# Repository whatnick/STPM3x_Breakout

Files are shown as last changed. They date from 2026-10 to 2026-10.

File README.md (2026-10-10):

# STPM3x Energy Metering Breakouts

Open-hardware development boards for the STMicroelectronics STPM32, STPM33,
and STPM34 energy-metering ASIC family.

The STPM3x devices combine precision analog conversion with on-chip
calculation of voltage, current, power, energy, and power-quality events. They
support current transformers, shunts, and Rogowski coils, with SPI or UART
host communication and CRC-protected data transfers.

This repository develops a consistent breakout family around all three channel
configurations:

| Board | Measurement channels | Best fit |
|---|---|---|
| **STPM32 Breakout** | 1 voltage + 1 current | Single-phase meters, smart appliances, and compact sensor development |
| **STPM33 Breakout** | 1 voltage + 2 current | Phase/neutral monitoring, tamper detection, and dual-current experiments |
| **STPM34 Breakout** | 2 voltage + 2 current | Split-phase systems, two independent circuits, and two-phase monitoring |

The STPM34 is the most capable member of this family, but it is not a complete
three-phase meter by itself. Applications requiring three simultaneous voltage
and current phases are better served by devices such as the ADE9000 or
ATM90E36.

## Place in the Whatnick ecosystem

The Whatnick energy-monitoring ecosystem includes breakout boards and drivers
for several metering architectures:

- **ATM90E26** for established single-phase SPI metering.
- **ATM90E32/ATM90E36** for three-phase monitoring.
- **ADE7763 and ADE7816** for Analog Devices single- and multi-channel designs.
- **ADE9000** for advanced polyphase metering and power-quality work.
- **CS5464 and CS5490** for Cirrus Logic single-phase applications.
- **MCP39F511 and MCP39F521** for Microchip calculation-engine devices.
- **V9203 and V93xx** for additional polyphase and single-phase platforms.
- **STPM3x** for a scalable STMicroelectronics family using a common register
  model across single-, dual-current, and dual-channel applications.

The aim is not only to expose IC pins. Each breakout should provide a known
hardware platform for driver development, calibration tools, sensor-interface
experiments, waveform analysis, and comparison between metering ASIC families.

## Intended software ecosystem

The three boards are intended to share one transport-independent STPM3x driver
core with device-specific channel capabilities layered on top. Planned software
support includes:

- Register definitions and typed configuration helpers.
- SPI and UART transports.
- CRC generation and checking.
- RMS, power, energy, event, and status access.
- Calibration and register-dump tools.
- Arduino and Python/MicroPython-facing APIs.
- Examples for CT, shunt, and Rogowski-coil measurements.

Keeping a common API across STPM32, STPM33, and STPM34 will allow applications
to move between board variants without maintaining three unrelated drivers.

## Hardware philosophy

These boards are intended as accessible bench-development platforms:

- Clearly separated analog sensor and digital host interfaces.
- Exposed pulse, interrupt, synchronization, clock, and enable signals.
- Space for channel-specific burden, divider, protection, and filtering
  networks.
- 3.3 V host compatibility.
- Compact breadboard modules or larger bench boards according to channel count.
- Readable safety labels and accessible test points.
- Open KiCad 10 source and project-local STPM3x symbols.

The STPM32 variant implements a complete compact front end for a
100 A:50 mA current-output CT and an isolated 9 VAC transformer secondary. It
uses a single 1x12 breadboard header, underside test pads, separate analog and
digital ground pours, and no field-wiring connectors. The STPM33 variant is
also complete, using the same isolated 9 VAC input with two 100 A:50 mA CT
channels, a 1x14 development header, five underside test pads, and a 55 x 40 mm
bench-board envelope. The STPM34 variant is complete on a 75 x 50 mm bench
board with two isolated 9 VAC channels, two 100 A:50 mA CT channels, separate
analog and host headers, and three underside test pads.

## Repository contents

- [`hardware/STPM32_Breakout`](hardware/STPM32_Breakout) - single voltage and
  current channel.
- [`hardware/STPM33_Breakout`](hardware/STPM33_Breakout) - single voltage and
  dual current channels.
- [`hardware/STPM34_Breakout`](hardware/STPM34_Breakout) - dual voltage and
  current channels.
- [`symbols/STPM3x.kicad_sym`](symbols/STPM3x.kicad_sym) - project-local,
  datasheet-verified symbols.
- [`docs/pin-map.md`](docs/pin-map.md) - family pin and package comparison.
- [`docs/design-requirements.md`](docs/design-requirements.md) - shared
  electrical, mechanical, and safety requirements.

## Safety

These are development boards, not certified energy meters. They must not be
connected directly to hazardous voltages without correctly rated isolation,
protection, fusing, spacing, enclosure, and appropriate electrical-safety
practices.

## License

Hardware design files are released under the
[TAPR Open Hardware License 1.0](LICENSE).

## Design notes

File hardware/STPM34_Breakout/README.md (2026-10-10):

# STPM34 Breakout

KiCad 10 open-hardware breakout for the STMicroelectronics STPM34 metering
ASIC. It measures two isolated voltage channels and two current-transformer
channels for split-phase, dual-circuit, and two-phase development.

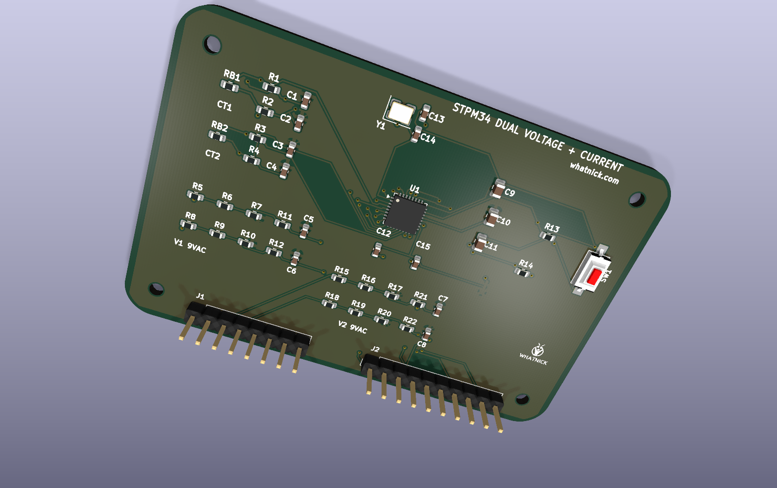
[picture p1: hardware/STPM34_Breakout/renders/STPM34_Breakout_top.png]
Top render


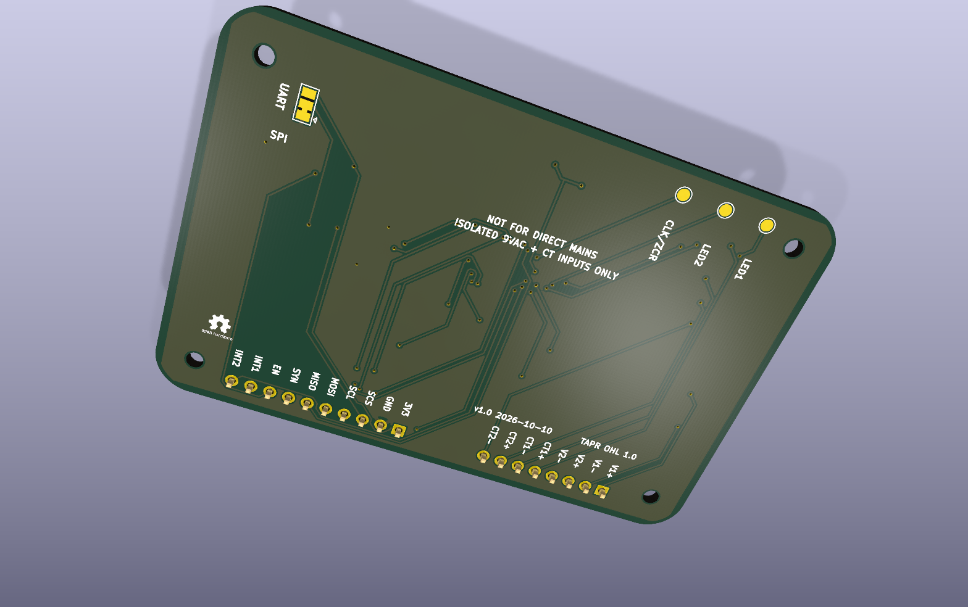
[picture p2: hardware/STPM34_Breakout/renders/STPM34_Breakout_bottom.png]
Bottom render


## Front end

- Supply: 3.3 V.
- Voltage inputs: two isolated 9 VAC transformer secondaries.
- Current inputs: two 100 A:50 mA CTs.
- Current burdens: 2.4 ohm differential, giving 120 mV RMS at 100 A.
- Current filters: 100 ohm series resistors and 330 nF capacitors.
- Voltage dividers: symmetric 200 kohm / 2.49 kohm per channel.
- Voltage filters: 1 kohm series resistors and 33 nF capacitors.
- Clock: 16 MHz crystal.
- Grounding: separate GNDA and DGND pours joined through NT1. NT1 is a copper
  net tie; no component is fitted there.

This is not an isolated mains-input board. Connect only isolated low-voltage
sources and follow applicable electrical-safety practices.

## Headers

J1 carries the analog inputs:

| Pin | Signal | Pin | Signal |
|---:|---|---:|---|
| 1 | V1AC_P | 5 | CT1_P |
| 2 | V1AC_N | 6 | CT1_N |
| 3 | V2AC_P | 7 | CT2_P |
| 4 | V2AC_N | 8 | CT2_N |

J2 carries power and the host interface:

| Pin | Signal | Pin | Signal |
|---:|---|---:|---|
| 1 | +3V3 | 6 | MISO/TXD |
| 2 | DGND | 7 | SYN |
| 3 | SCS | 8 | EN |
| 4 | SCL | 9 | INT1 |
| 5 | MOSI/RXD | 10 | INT2 |

Underside pads expose LED1, LED2, and CLKOUT/ZCR.

## SPI/UART selector

STPM34 supports SPI or UART, not I2C. SJ1 biases SCS through R14 at power-up:

- Pads 1-2 are closed by default, selecting SPI with a DGND bias.
- For UART, cut pads 1-2 and bridge pads 2-3 to bias SCS to +3V3.
- Press SW1 after changing SJ1 so EN is asserted low and the interface mode is
  sampled again.

## Rebuilding

Run the scripts from the repository root:

```powershell
python .\scripts\build_stpm34_schematic.py
python .\scripts\apply_stpm34_bom.py
& "C:\Program Files\KiCad\10.0\bin\python.exe" .\scripts\build_stpm34_pcb.py
```

Routing uses Freerouting with Java 25:

```powershell
$env:JAVA25 = "C:\Program Files\Eclipse Adoptium\jre-25.0.4.101-hotspot\bin\java.exe"
$env:FREEROUTING_JAR = "C:\path\to\freerouting-2.4.1.jar"
& "C:\Program Files\KiCad\10.0\bin\python.exe" .\scripts\route_stpm34.py
& "C:\Program Files\KiCad\10.0\bin\python.exe" .\scripts\finalize_stpm34_pcb.py
```

The checked-in routed PCB is the production source. Reconstruction scripts
capture the electrical design, 75 x 50 mm rounded envelope, placement,
routing workflow, ground pours, markings, and project-local 3D/logo assets.

## Manufacturing outputs

```powershell
python .\scripts\apply_stpm34_bom.py
python .\scripts\render_stpm34.py
python .\scripts\generate_stpm34_gerbers.py
```

The Elecrow BOM is written to `manufacturing`. Gerbers, separate PTH/NPTH
drills, Gerber job data, front/rear position CSVs, and the upload ZIP are
written to `gerber`. The BOM contains 17 grouped unique parts and 44 fitted
components.

## Breadboard bench scene

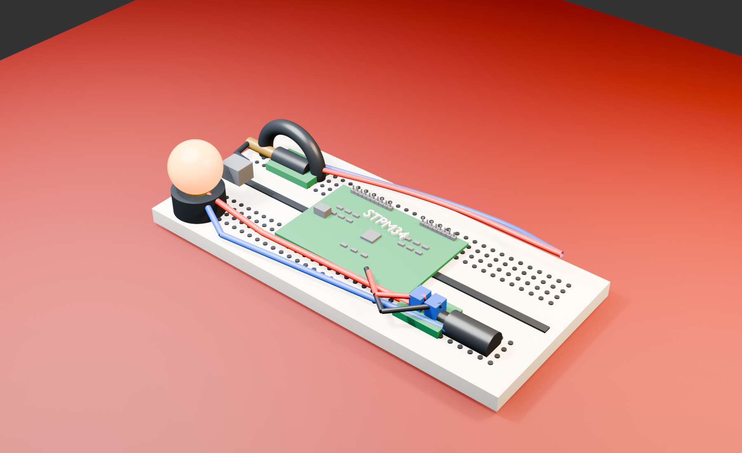
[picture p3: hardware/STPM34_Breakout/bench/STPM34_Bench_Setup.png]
STPM34 isolated low-voltage bench setup


The FreeCAD and Blender scene illustrates a safe low-voltage demonstration:
an isolated 9 VAC barrel adapter feeds the voltage input and a 9 VAC lamp,
while a YHDC current-transformer clamp surrounds one lamp conductor and
connects through a stereo-jack breakout. The composition is an original
render inspired by common Whatnick bench practice and the supplied Tindie
reference photograph; it is not a literal reconstruction of that photograph.

Generate the editable FreeCAD model, intermediate STEP/OBJ geometry, Blender
scene, and final PNG from the repository root:

```powershell
& "C:\Program Files\FreeCAD 0.19\bin\FreeCADCmd.exe" .\scripts\build_stpm34_bench_freecad.py
& "C:\Program Files\Blender Foundation\Blender 5.2\blender.exe" --background --python .\scripts\render_stpm34_bench_blender.py
```

The checked-in deliverables are the `.FCStd`, `.blend`, and `.png` files.
Intermediate STEP and OBJ exports are regenerated locally and ignored by Git.

**Safety:** the scene represents an isolated 9 VAC test circuit only. Never
connect mains voltage directly to a breadboard, the STPM34 analog header, or
the rendered barrel/stereo breakout arrangement.

## Validation

KiCad 10 ERC and DRC are mandatory before fabrication export. The Gerber
generator enforces zero ERC/DRC violations and zero unconnected items before
creating the package.

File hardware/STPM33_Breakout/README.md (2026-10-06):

# STPM33 Breakout

KiCad 10 open-hardware breakout for the STMicroelectronics STPM33 metering
ASIC. It measures one isolated voltage channel and two current-transformer
channels, making it useful for phase/neutral comparison, tamper detection, and
two-current experiments sharing one voltage reference.

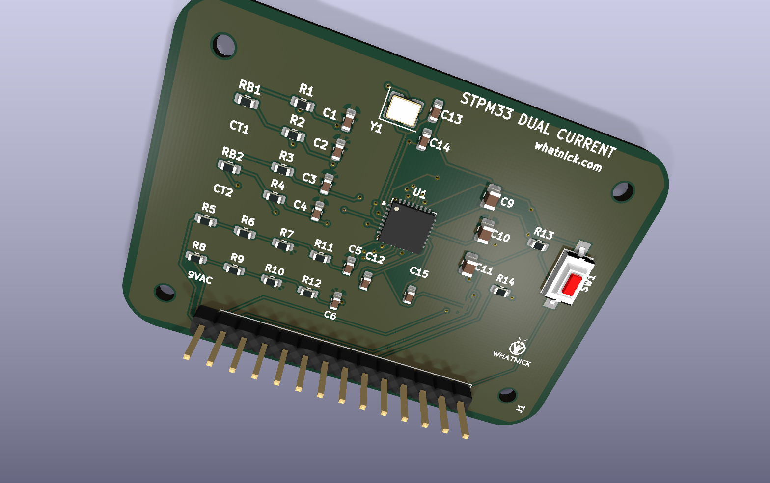
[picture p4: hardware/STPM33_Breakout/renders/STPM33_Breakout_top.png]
Top render


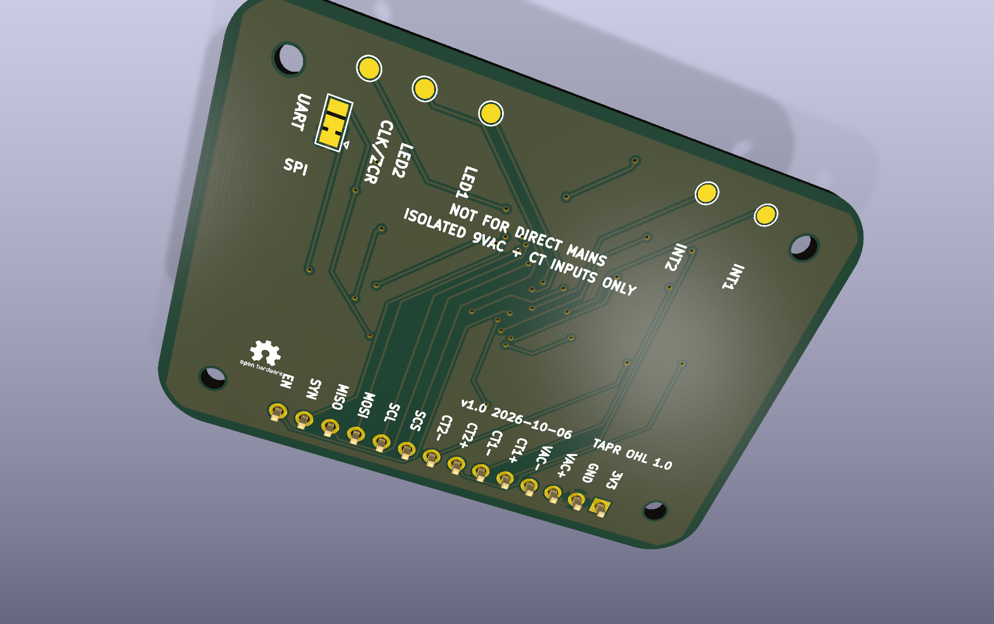
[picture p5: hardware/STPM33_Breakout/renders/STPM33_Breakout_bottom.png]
Bottom render


## Front end

- Supply: 3.3 V.
- Voltage input: isolated 9 VAC transformer secondary only.
- Current inputs: two 100 A:50 mA CTs.
- Current burdens: 2.4 ohm differential, giving 120 mV RMS at 100 A.
- Current filters: 100 ohm series resistors and 330 nF capacitors.
- Voltage divider: symmetric 200 kohm / 2.49 kohm legs.
- Voltage filters: 1 kohm series resistors and 33 nF capacitors.
- Clock: 16 MHz crystal.
- Grounding: separate GNDA and DGND pours joined through NT1. NT1 is a copper
  net tie; no component is fitted there.

This is not an isolated mains-input board. Connect only isolated low-voltage
sources and follow applicable electrical-safety practices.

## J1 pin map

| Pin | Signal | Pin | Signal |
|---:|---|---:|---|
| 1 | +3V3 | 8 | CT2_N |
| 2 | DGND | 9 | SCS |
| 3 | VAC_P | 10 | SCL |
| 4 | VAC_N | 11 | MOSI/RXD |
| 5 | CT1_P | 12 | MISO/TXD |
| 6 | CT1_N | 13 | SYN |
| 7 | CT2_P | 14 | EN |

Underside pads expose INT1, INT2, LED1, LED2, and CLKOUT/ZCR.

## SPI/UART selector

STPM33 supports SPI or UART, not I2C. SJ1 biases SCS through R14 at power-up:

- Pads 1-2 are closed by default, selecting SPI with a DGND bias.
- For UART, cut pads 1-2 and bridge pads 2-3 to bias SCS to +3V3.
- Press SW1 after changing SJ1 so EN is asserted low and the interface mode is
  sampled again.

## Rebuilding

Run the scripts from the repository root:

```powershell
python .\scripts\build_stpm33_schematic.py
python .\scripts\apply_stpm33_bom.py
& "C:\Program Files\KiCad\10.0\bin\python.exe" .\scripts\build_stpm33_pcb.py
```

Routing uses Freerouting with Java 25:

```powershell
$env:JAVA25 = "C:\Program Files\Eclipse Adoptium\jre-25.0.4.101-hotspot\bin\java.exe"
$env:FREEROUTING_JAR = "C:\path\to\freerouting-2.4.1.jar"
& "C:\Program Files\KiCad\10.0\bin\python.exe" .\scripts\route_stpm33.py
& "C:\Program Files\KiCad\10.0\bin\python.exe" .\scripts\finalize_stpm33_pcb.py
```

The checked-in routed PCB is the production source. Reconstruction scripts
capture the schematic, mechanical envelope, placement, routing workflow,
ground pours, markings, and project-local 3D/logo assets.

## Manufacturing outputs

```powershell
python .\scripts\apply_stpm33_bom.py
python .\scripts\render_stpm33.py
python .\scripts\generate_stpm33_gerbers.py
```

The Elecrow BOM is written to `manufacturing`. Gerbers, separate PTH/NPTH
drills, Gerber job data, front/rear position CSVs, and the upload ZIP are
written to `gerber`. The BOM contains 16 grouped unique parts and 33 fitted
components.

## Validation

KiCad 10 ERC and DRC are mandatory before fabrication export. The Gerber
generator enforces zero ERC/DRC violations and zero unconnected items before
creating the package.

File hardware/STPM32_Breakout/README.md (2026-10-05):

# STPM32 breakout

Compact KiCad 10 development board for the single-voltage, single-current
STMicroelectronics STPM32 energy-metering ASIC.

## 3D renders

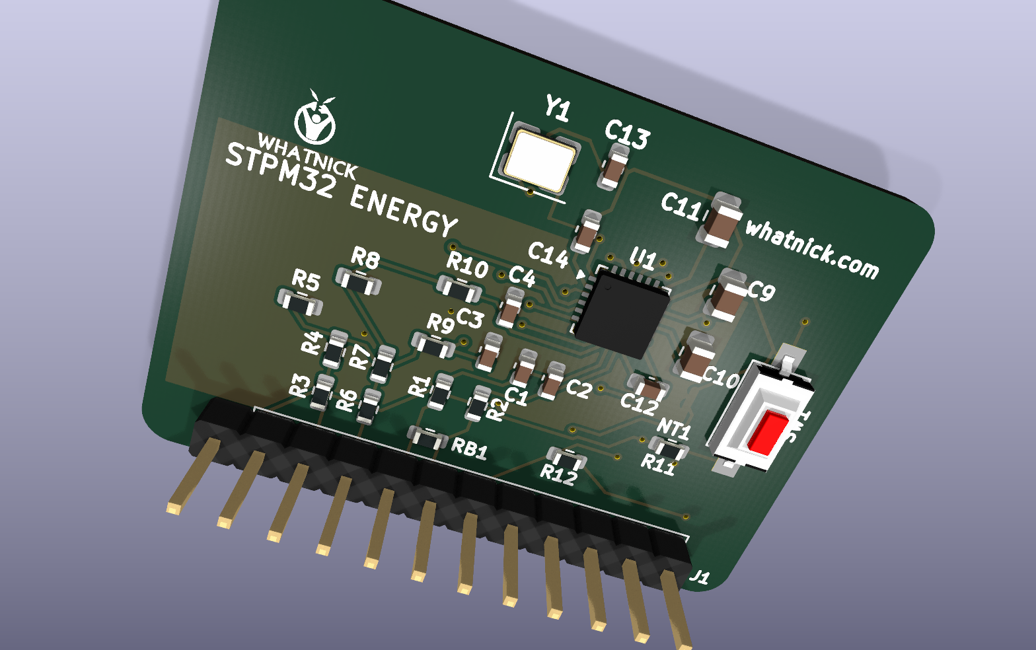
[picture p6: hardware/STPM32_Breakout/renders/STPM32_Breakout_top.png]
Populated STPM32 breakout top render


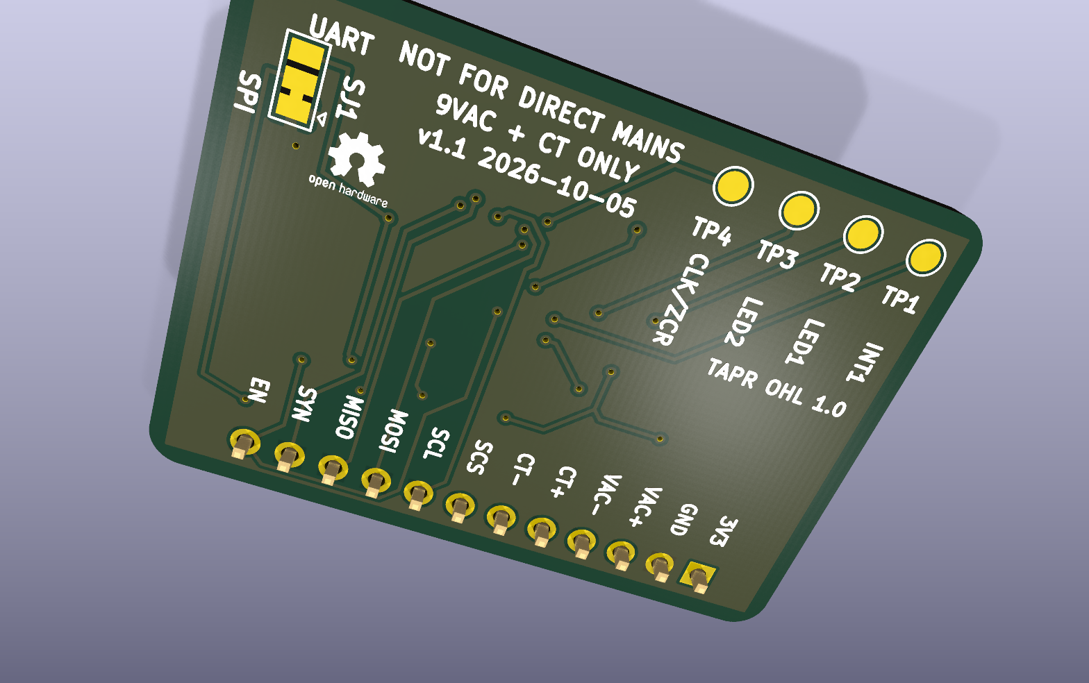
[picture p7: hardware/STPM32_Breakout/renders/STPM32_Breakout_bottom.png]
STPM32 breakout bottom render


## Implemented front end

- **Current input:** 100 A:50 mA current-output CT.
- **Burden:** 2.4 ohm differential, producing 120 mV RMS at 100 A.
- **Current filter:** 100 ohm series and 330 nF shunt on each differential leg,
  approximately 4.8 kHz.
- **Voltage input:** isolated 9 VAC transformer secondary.
- **Voltage divider:** 200 kohm / 2.49 kohm on each conductor, approximately
  81.3:1 differential scaling.
- **Voltage filter:** 1 kohm series and 33 nF shunt on each differential leg,
  approximately 4.8 kHz.
- **Clock:** 16 MHz crystal with 15 pF load capacitors.
- **Interface selector:** STPM32 supports SPI and UART, not I2C. SJ1 is a
  three-pad solder jumper with pads 1-2 closed by default, weakly pulling SCS
  low through R12 for SPI. For UART, cut the 1-2 bridge and solder 2-3 so R12
  weakly pulls SCS high. The resistor preserves host control of SCS in SPI mode.

At 9 VAC differential input, the voltage channel receives approximately
111 mV RMS, or 157 mV peak. Both analog channels remain below the STPM32
maximum differential input of +/-300 mV at their stated full-scale inputs.

## Breadboard header

| Pin | Signal | Pin | Signal |
|---:|---|---:|---|
| 1 | +3V3 | 7 | SCS |
| 2 | DGND | 8 | SCL |
| 3 | VAC_P | 9 | MOSI/RXD |
| 4 | VAC_N | 10 | MISO/TXD |
| 5 | CT_P | 11 | SYN |
| 6 | CT_N | 12 | EN |

INT1, LED1, LED2, and CLKOUT/ZCR are available on underside test pads.

## Mechanical and validation status

- 38.2 x 28.04 mm rounded board.
- Single long-edge 1x12, 2.54 mm header.
- No screw terminals, audio jacks, or direct-mains connector.
- Routed two-layer PCB with separate AGND and DGND pours joined through the
  three-pad analog/reference/digital ground net tie.
- Production silkscreen uses 0.8 x 0.8 mm component and signal labels with
  0.2 mm stroke, project-local Whatnick and OSHW logos, and explicit revision
  and build-date marking.
- U1 uses the project-local
  `models/step/STPM32_VQFN24_4x4_EP2.45.step` model. It matches the 4 x 4 mm,
  1.0 mm-high, 0.5 mm-pitch VQFN-24 envelope and nominal 2.45 x 2.45 mm
  exposed pad instead of relying on the missing similarly named KiCad library
  model. Geometry and orientation were cross-checked against ST's
  `STPM32.STEP` vendor model dated 2024-01-25; the vendor file is not
  redistributed.
- ERC: zero violations.
- DRC: zero violations and zero unconnected pads.

Regenerate the model and committed renders with:

```powershell
python -m pip install cadquery
python .\scripts\create_stpm32_qfn_step.py
python .\scripts\render_stpm32.py
```

## Gerber fabrication package

Generate the KiCad 10 fabrication outputs with:

```powershell
python .\scripts\generate_stpm32_gerbers.py
```

The script runs ERC and DRC before exporting the two copper layers, solder
masks, front and rear silkscreens, front paste, board outline, separate
plated/non-plated Excellon drill files, and front/rear component position CSV
files. Outputs are written to:

- `hardware/STPM32_Breakout/gerber/`
- `hardware/STPM32_Breakout/gerber/STPM32_Breakout_Gerbers.zip`

Upload the ZIP through Elecrow's PCB manufacturing web form. Elecrow does not
currently document a public PCB order or Gerber-upload API, so no account
credentials are required by this repository.

## Elecrow assembly BOM

The initial production selection uses exact manufacturer part numbers and LCSC
catalog identifiers so Elecrow can quote turnkey sourcing without substituting
parts from value-only descriptions. Precision 0.1%, 25 ppm/C resistors are
specified for the voltage-divider ratios; the remaining resistors are 1%.
Filter capacitors use X7R dielectric, crystal load capacitors use C0G, and the
16 MHz crystal is specified for 12 pF load capacitance. The selected 2.4 ohm
burden is suitable for development builds; use a lower-TCR burden selection
before claiming calibration-grade temperature stability.

Apply the sourcing metadata and regenerate the quote BOM with:

```powershell
python .\scripts\apply_stpm32_bom.py
```

The generated file is:

- `manufacturing/STPM32_Breakout_Elecrow_BOM.csv`

Assembly notes:

- U1 and all other SMT parts are intended for Elecrow placement.
- J1 is the only THT line and should be quoted separately; confirm that the
  fitted pin protrusion is suitable for breadboard use.
- TP1-TP4 and NT1 are PCB features, not purchasable components, and are
  excluded from the schematic BOM and placement outputs.
- Whatnick and OSHW logo footprints are excluded from BOM and placement files.
- Verify live stock, pricing, and approved substitutions when requesting each
  production quote.

## Safety

The voltage input is for an isolated 9 VAC transformer secondary only. This
development board is not a certified isolation barrier and must never be
connected directly to mains.

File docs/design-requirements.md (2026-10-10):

# STPM3x breakout design requirements

## Authoritative source

- STMicroelectronics, `DS10272 Rev 14`, *STPM32, STPM33, STPM34 ASSP for
  metering applications with up to four independent 24-bit 2nd-order
  sigma-delta ADCs, 4 MHz OSF and 2 embedded PGLNA*.
- The source PDF is not committed. Download the current revision from the
  [STPM34 product page](https://www.st.com/en/data-converters/stpm34.html).

## Shared electrical blocks

- 2.95 V to 3.65 V supply; nominal 3.3 V.
- 1 uF between VCC and ground.
- 1 uF between VDDA and GNDA.
- 4.7 uF between VDDD and GNDD.
- 100 nF from each implemented VREF output to GND_REF.
- 16 MHz crystal or an external clock satisfying the datasheet limits.
- EN exposed with a defined pull state and reset access.
- Interface selection is explicit:
  - STPM32 supports SPI and UART; it does not support I2C.
  - SCS low at power-up: SPI.
  - SCS high at power-up: UART.
  - A three-pad selector biases SCS through a resistor rather than hard-strapping
    it, preserving normal SPI chip-select operation.
  - The manufactured default bridges DGND to the bias resistor for SPI; UART
    requires cutting that bridge and connecting the bias resistor to +3V3.
- SYN, LED1, LED2, INT1, available INT2, and CLKOUT/ZCR remain accessible.
- Digital interface signals use a grouped 2.54 mm development header or
  equivalent compact connector.

## Analog design gates

Do not copy divider or burden values without tying them to the intended sensor
and range. The datasheet example is informative rather than universal:

- Differential analog pins are limited to +/-300 mV.
- Current-channel PGA ranges are +/-300, +/-150, +/-75, and +/-37.5 mV.
- Example line-voltage divider ratios are 1:1650 for 230 V RMS and 1:830 for
  110 V RMS.
- Example sensor sensitivities are 0.15 mV/A for Rogowski, 2.4 mV/A for CT,
  and 0.3 mV/A for shunt sensing.
- The reference design uses 150 pF input capacitors and channel-specific
  resistor networks; values must be re-derived for the selected transducer.

Every analog path must remain readable as:

```text
field connector -> burden/divider/protection -> anti-alias network -> IC pin
```

Use connector-side suffixes such as `_J` and IC-side signal names such as
`VIP1`, `VIN1`, `IIP1`, and `IIN1`.

## Mechanical formats

The STPM33 and STPM34 bench boards use:

- A rounded bench-board envelope sized for the implemented channel count.
- 5.08 mm rounded corners.
- Four M2 NPTH holes, 2.2 mm drill.
- Metering IC near the center.
- Analog field/sensor region on the left.
- Digital power/debug region on the right.
- Clock and reference support immediately adjacent to U1 when populated.
- Board identity on F.SilkS.
- URL, TAPR OHL notice, and `NOT ISOLATED` warning on B.SilkS.

The implemented STPM32 board uses the compact Whatnick breakout format:

- 38.2 x 28.04 mm rounded outline.
- One long-edge 1x12, 2.54 mm breadboard header.
- Analog inputs enter through header pins; no screw terminals or audio jacks.
- INT1, LED1, LED2, and CLKOUT/ZCR use underside test pads.
- Separate AGND and DGND copper pours join through the three-pad net tie.
- `NOT FOR DIRECT MAINS` and isolated-source warnings remain visible.

## Variant intent

### STPM32

- One voltage and one current channel.
- Smallest BOM and lowest current consumption.
- Implemented for a 100 A:50 mA current-output CT and isolated 9 VAC voltage
  transformer.
- 2.4 ohm differential burden gives 120 mV RMS at 100 A.
- Symmetric 200 kohm / 2.49 kohm dividers give approximately 111 mV RMS at
  9 VAC differential input.
- Current and voltage anti-alias filters are approximately 4.8 kHz.
- Target: compact single-phase metering and driver development.

### STPM33

- One voltage and two current channels.
- Implemented for two 100 A:50 mA CTs and one isolated 9 VAC transformer.
- Each CT uses a 2.4 ohm differential burden and approximately 4.8 kHz input
  filtering.
- The voltage channel uses symmetric 200 kohm / 2.49 kohm dividers and
  approximately 4.8 kHz filtering.
- A 1x14 development header exposes both analog inputs and the host interface.
- Five underside test pads expose INT1, INT2, LED1, LED2, and CLKOUT/ZCR.
- Target: phase/neutral monitoring, tamper experiments, or two current sensors
  sharing one voltage channel.

### STPM34

- Two voltage and two current channels.
- Implemented for two 100 A:50 mA CTs and two isolated 9 VAC transformers.
- Each CT uses a 2.4 ohm differential burden and approximately 4.8 kHz input
  filtering.
- Each voltage channel uses symmetric 200 kohm / 2.49 kohm dividers and
  approximately 4.8 kHz filtering.
- Separate 1x8 analog and 1x10 host headers keep field and digital wiring
  grouped.
- Three underside test pads expose LED1, LED2, and CLKOUT/ZCR; INT1 and INT2
  are exposed on the host header.
- The implemented board envelope is 75 x 50 mm with 5.08 mm rounded corners.
- Target: dual-circuit, split-phase, or two-phase development.
- It is not a complete three-phase meter by itself.

## Validation gates

- Project-local symbols match the datasheet pin table.
- Final footprints match the QFN mechanical tables and recommended land
  patterns.
- ERC: zero errors.
- Placement DRC: zero new mechanical errors.
- Final DRC: zero errors and zero unconnected items.
- Purchasing fields are present on every sourced schematic symbol:
  `Manufacturer`, `MPN`, `Description`, `DigiKey`, and `Mouser`.

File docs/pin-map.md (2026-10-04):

# STPM3x verified pin map

Source: STMicroelectronics DS10272 Rev 14, Figures 4-6 and Table 1.

## Shared pins

| Function | STPM34 | STPM33 | STPM32 |
|---|---:|---:|---:|
| CLKOUT/ZCR | 1 | 1 | 1 |
| CLKIN/XTAL2 | 2 | 2 | 2 |
| XTAL1 | 3 | 3 | 3 |
| LED1 | 4 | 4 | 4 |
| LED2 | 5 | 5 | 5 |
| INT1 | 6 | 6 | 6 |
| INT2 | 7 | 7 | - |
| EN | 8 | 8 | 7 |
| VIP1 | 9 | 9 | 8 |
| VIN1 | 10 | 10 | 9 |
| IIP1 | 11 | 11 | 10 |
| IIN1 | 12 | 12 | 11 |
| IIN2 | 13 | 13 | - |
| IIP2 | 14 | 14 | - |
| VIN2 | 15 | - | - |
| VIP2 | 16 | - | - |
| VREF1 | 17 | 17 | 12 |
| GND_REF | 18 | 18 | 13 |
| VREF2 | 19 | 19 | - |
| GNDA | 20 | 20 | 14 |
| VDDA | 21 | 21 | 15 |
| GND_REG | 22 | 22 | 16 |
| VCC | 23 | 23 | 17 |
| NC | 24 | 15, 16, 24, 25 | - |
| GNDD | 25, 26 | 26 | 18 |
| VDDD | 27 | 27 | 19 |
| SYN | 28 | 28 | 20 |
| SCS | 29 | 29 | 21 |
| SCL | 30 | 30 | 22 |
| MOSI/RXD | 31 | 31 | 23 |
| MISO/TXD | 32 | 32 | 24 |

## Package selection

| Device | Package | Datasheet exposed-pad size | Scaffold footprint |
|---|---|---:|---|
| STPM32 | QFN24L, 4 x 4 mm, 0.5 mm pitch | 2.45 x 2.45 mm typical | `VQFN-24-1EP_4x4mm_P0.5mm_EP2.45x2.45mm` |
| STPM33 | QFN32L, 5 x 5 mm, 0.5 mm pitch | 3.45 x 3.45 mm typical | `QFN-32-1EP_5x5mm_P0.5mm_EP3.45x3.45mm` |
| STPM34 | QFN32L, 5 x 5 mm, 0.5 mm pitch | 3.45 x 3.45 mm typical | `QFN-32-1EP_5x5mm_P0.5mm_EP3.45x3.45mm` |

The datasheet pin table does not assign a numbered electrical function to the
package exposed pad. Its final net assignment remains an explicit design-review
item rather than being guessed in the symbols. Thermal-via geometry is also
deferred until that connection and the assembly process are confirmed.

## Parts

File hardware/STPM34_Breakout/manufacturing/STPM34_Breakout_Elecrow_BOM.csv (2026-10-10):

Reference Designator | Quantity | Manufacturer | Manufacturer Part Number | Description / Value | Package / Footprint | LCSC Part Number | Assembly Type | Purchase URL | DigiKey | Mouser | Notes
U1 | 1 | STMicroelectronics | STPM34TR | Dual-voltage, dual-current-channel energy-metering ASIC | QFN-32-EP, 5 x 5 mm, 0.5 mm pitch; Package_DFN_QFN:QFN-32-1EP_5x5mm_P0.5mm_EP3.45x3.45mm | C129475 | SMT | https://www.lcsc.com/product-detail/C129475.html | https://www.digikey.com/en/products/result?keywords=STPM34TR | https://www.mouser.com/c/?q=STPM34TR | Inspect exposed-pad paste and voiding during DFM review.
R1,R2,R3,R4 | 4 | YAGEO | RC0603FR-07100RL | 100 ohm, 1%, 0.1 W thick-film resistor | 0603 (1608 Metric); Resistor_SMD:R_0603_1608Metric | C105588 | SMT | https://www.lcsc.com/product-detail/C105588.html | https://www.digikey.com/en/products/result?keywords=RC0603FR-07100RL | https://www.mouser.com/c/?q=RC0603FR-07100RL
R5,R6,R8,R9,R15,R16,R18,R19 | 8 | YAGEO | RT0603BRD07100KL | 100 kohm, 0.1%, 25 ppm/C thin-film resistor | 0603 (1608 Metric); Resistor_SMD:R_0603_1608Metric | C122538 | SMT | https://www.lcsc.com/product-detail/C122538.html | https://www.digikey.com/en/products/result?keywords=RT0603BRD07100KL | https://www.mouser.com/c/?q=RT0603BRD07100KL | Use one lot for all eight voltage-divider resistors.
R7,R10,R17,R20 | 4 | YAGEO | RT0603BRD072K49L | 2.49 kohm, 0.1%, 25 ppm/C thin-film resistor | 0603 (1608 Metric); Resistor_SMD:R_0603_1608Metric | C861299 | SMT | https://www.lcsc.com/product-detail/C861299.html | https://www.digikey.com/en/products/result?keywords=RT0603BRD072K49L | https://www.mouser.com/c/?q=RT0603BRD072K49L | Use one lot for all four matched voltage-divider low sides.
R11,R12,R21,R22 | 4 | YAGEO | RC0603FR-071KL | 1 kohm, 1%, 0.1 W thick-film resistor | 0603 (1608 Metric); Resistor_SMD:R_0603_1608Metric | C22548 | SMT | https://www.lcsc.com/product-detail/C22548.html | https://www.digikey.com/en/products/result?keywords=RC0603FR-071KL | https://www.mouser.com/c/?q=RC0603FR-071KL
R13,R14 | 2 | YAGEO | RC0603FR-0710KL | 10 kohm, 1%, 0.1 W thick-film resistor | 0603 (1608 Metric); Resistor_SMD:R_0603_1608Metric | C98220 | SMT | https://www.lcsc.com/product-detail/C98220.html | https://www.digikey.com/en/products/result?keywords=RC0603FR-0710KL | https://www.mouser.com/c/?q=RC0603FR-0710KL
RB1,RB2 | 2 | YAGEO | RC0603FR-072R4L | 2.4 ohm, 1%, 0.1 W CT burden resistor | 0603 (1608 Metric); Resistor_SMD:R_0603_1608Metric | C137746 | SMT | https://www.lcsc.com/product-detail/C137746.html | https://www.digikey.com/en/products/result?keywords=RC0603FR-072R4L | https://www.mouser.com/c/?q=RC0603FR-072R4L | About 6 mW at 50 mA RMS. The 200 ppm/C TCR is suitable for development; use a lower-TCR burden for calibration-grade builds.
C1,C2,C3,C4 | 4 | CCTC | TCC0603X7R334K500CT | 330 nF, 50 V, 10%, X7R MLCC | 0603 (1608 Metric); Capacitor_SMD:C_0603_1608Metric | C282682 | SMT | https://www.lcsc.com/product-detail/C282682.html | https://www.digikey.com/en/products/result?keywords=TCC0603X7R334K500CT | https://www.mouser.com/c/?q=TCC0603X7R334K500CT
C5,C6,C7,C8 | 4 | Samsung Electro-Mechanics | CL10B333KB8NNNC | 33 nF, 50 V, 10%, X7R MLCC | 0603 (1608 Metric); Capacitor_SMD:C_0603_1608Metric | C21117 | SMT | https://www.lcsc.com/product-detail/C21117.html | https://www.digikey.com/en/products/result?keywords=CL10B333KB8NNNC | https://www.mouser.com/c/?q=CL10B333KB8NNNC
C12,C15 | 2 | Samsung Electro-Mechanics | CL10B104KB8NNNC | 100 nF, 50 V, 10%, X7R MLCC | 0603 (1608 Metric); Capacitor_SMD:C_0603_1608Metric | C1591 | SMT | https://www.lcsc.com/product-detail/C1591.html | https://www.digikey.com/en/products/result?keywords=CL10B104KB8NNNC | https://www.mouser.com/c/?q=CL10B104KB8NNNC
C13,C14 | 2 | Samsung Electro-Mechanics | CL10C150JB8NNNC | 15 pF, 50 V, 5%, C0G MLCC | 0603 (1608 Metric); Capacitor_SMD:C_0603_1608Metric | C1644 | SMT | https://www.lcsc.com/product-detail/C1644.html | https://www.digikey.com/en/products/result?keywords=CL10C150JB8NNNC | https://www.mouser.com/c/?q=CL10C150JB8NNNC
C9,C10 | 2 | Samsung Electro-Mechanics | CL21B105KAFNNNE | 1 uF, 25 V, 10%, X7R MLCC | 0805 (2012 Metric); Capacitor_SMD:C_0805_2012Metric | C116352 | SMT | https://www.lcsc.com/product-detail/C116352.html | https://www.digikey.com/en/products/result?keywords=CL21B105KAFNNNE | https://www.mouser.com/c/?q=CL21B105KAFNNNE
C11 | 1 | Samsung Electro-Mechanics | CL21A475KOFNNNG | 4.7 uF, 16 V, 10%, X5R MLCC | 0805 (2012 Metric); Capacitor_SMD:C_0805_2012Metric | C16194928 | SMT | https://www.lcsc.com/product-detail/C16194928.html | https://www.digikey.com/en/products/result?keywords=CL21A475KOFNNNG | https://www.mouser.com/c/?q=CL21A475KOFNNNG
Y1 | 1 | YXC | X322516MOB4SI | 16 MHz, 12 pF load crystal | SMD3225-4P; Crystal:Crystal_SMD_3225-4Pin_3.2x2.5mm | C12668 | SMT | https://www.lcsc.com/product-detail/C12668.html | https://www.digikey.com/en/products/result?keywords=X322516MOB4SI | https://www.mouser.com/c/?q=X322516MOB4SI | 12 pF load is consistent with two 15 pF capacitors plus estimated pin and PCB stray capacitance; verify oscillator margin on prototypes.
SW1 | 1 | C&K | RS-282G05A3-SMRT | Momentary SPST reset switch | C&K RS-282G05A3 SMD; Button_Switch_SMD:SW_SPST_CK_RS282G05A3 | C221930 | SMT | https://www.lcsc.com/product-detail/C221930.html | https://www.digikey.com/en/products/result?keywords=RS-282G05A3-SMRT | https://www.mouser.com/c/?q=RS-282G05A3-SMRT
J1 | 1 | XFCN | PZ254V-11-08P | Single-row analog-input male pin header | 1x8, 2.54 mm pitch, vertical THT; Connector_PinHeader_2.54mm:PinHeader_1x08_P2.54mm_Vertical | C492407 | THT | https://www.lcsc.com/product-detail/C492407.html | https://www.digikey.com/en/products/result?keywords=PZ254V-11-08P | https://www.mouser.com/c/?q=PZ254V-11-08P | Quote THT assembly separately and confirm pin protrusion suits breadboards.
J2 | 1 | XFCN | PZ254V-11-10P | Single-row host-interface male pin header | 1x10, 2.54 mm pitch, vertical THT; Connector_PinHeader_2.54mm:PinHeader_1x10_P2.54mm_Vertical | C492409 | THT | https://www.lcsc.com/product-detail/C492409.html | https://www.digikey.com/en/products/result?keywords=PZ254V-11-10P | https://www.mouser.com/c/?q=PZ254V-11-10P | Quote THT assembly separately and confirm mating header geometry.

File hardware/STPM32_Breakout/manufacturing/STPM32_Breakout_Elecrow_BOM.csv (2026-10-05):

Reference Designator | Quantity | Manufacturer | Manufacturer Part Number | Description / Value | Package / Footprint | LCSC Part Number | Assembly Type | Purchase URL | Notes
U1 | 1 | STMicroelectronics | STPM32TR | Single-phase energy-metering ASIC | VQFN-24-EP, 4 x 4 mm, 0.5 mm pitch; Package_DFN_QFN:VQFN-24-1EP_4x4mm_P0.5mm_EP2.45x2.45mm | C128380 | SMT | https://www.lcsc.com/product-detail/C128380.html | Inspect exposed-pad paste and voiding during DFM review.
R1,R2 | 2 | YAGEO | RC0603FR-07100RL | 100 ohm, 1%, 0.1 W thick-film resistor | 0603 (1608 Metric); Resistor_SMD:R_0603_1608Metric | C105588 | SMT | https://www.lcsc.com/product-detail/C105588.html
R3,R4,R6,R7 | 4 | YAGEO | RT0603BRD07100KL | 100 kohm, 0.1%, 25 ppm/C thin-film resistor | 0603 (1608 Metric); Resistor_SMD:R_0603_1608Metric | C122538 | SMT | https://www.lcsc.com/product-detail/C122538.html | Use one lot for all four voltage-divider resistors.
R5,R8 | 2 | YAGEO | RT0603BRD072K49L | 2.49 kohm, 0.1%, 25 ppm/C thin-film resistor | 0603 (1608 Metric); Resistor_SMD:R_0603_1608Metric | C861299 | SMT | https://www.lcsc.com/product-detail/C861299.html | Use one lot for the matched voltage-divider low sides.
R9,R10 | 2 | YAGEO | RC0603FR-071KL | 1 kohm, 1%, 0.1 W thick-film resistor | 0603 (1608 Metric); Resistor_SMD:R_0603_1608Metric | C22548 | SMT | https://www.lcsc.com/product-detail/C22548.html
R11,R12 | 2 | YAGEO | RC0603FR-0710KL | 10 kohm, 1%, 0.1 W thick-film resistor | 0603 (1608 Metric); Resistor_SMD:R_0603_1608Metric | C98220 | SMT | https://www.lcsc.com/product-detail/C98220.html
RB1 | 1 | YAGEO | RC0603FR-072R4L | 2.4 ohm, 1%, 0.1 W CT burden resistor | 0603 (1608 Metric); Resistor_SMD:R_0603_1608Metric | C137746 | SMT | https://www.lcsc.com/product-detail/C137746.html | About 6 mW at 50 mA RMS. The 200 ppm/C TCR is suitable for development; use a lower-TCR burden for calibration-grade builds.
C1,C2 | 2 | CCTC | TCC0603X7R334K500CT | 330 nF, 50 V, 10%, X7R MLCC | 0603 (1608 Metric); Capacitor_SMD:C_0603_1608Metric | C282682 | SMT | https://www.lcsc.com/product-detail/C282682.html
C3,C4 | 2 | Samsung Electro-Mechanics | CL10B333KB8NNNC | 33 nF, 50 V, 10%, X7R MLCC | 0603 (1608 Metric); Capacitor_SMD:C_0603_1608Metric | C21117 | SMT | https://www.lcsc.com/product-detail/C21117.html
C12 | 1 | Samsung Electro-Mechanics | CL10B104KB8NNNC | 100 nF, 50 V, 10%, X7R MLCC | 0603 (1608 Metric); Capacitor_SMD:C_0603_1608Metric | C1591 | SMT | https://www.lcsc.com/product-detail/C1591.html
C13,C14 | 2 | Samsung Electro-Mechanics | CL10C150JB8NNNC | 15 pF, 50 V, 5%, C0G MLCC | 0603 (1608 Metric); Capacitor_SMD:C_0603_1608Metric | C1644 | SMT | https://www.lcsc.com/product-detail/C1644.html
C9,C10 | 2 | Samsung Electro-Mechanics | CL21B105KAFNNNE | 1 uF, 25 V, 10%, X7R MLCC | 0805 (2012 Metric); Capacitor_SMD:C_0805_2012Metric | C116352 | SMT | https://www.lcsc.com/product-detail/C116352.html
C11 | 1 | Samsung Electro-Mechanics | CL21A475KOFNNNG | 4.7 uF, 16 V, 10%, X5R MLCC | 0805 (2012 Metric); Capacitor_SMD:C_0805_2012Metric | C16194928 | SMT | https://www.lcsc.com/product-detail/C16194928.html
Y1 | 1 | YXC | X322516MOB4SI | 16 MHz, 12 pF load crystal | SMD3225-4P; Crystal:Crystal_SMD_3225-4Pin_3.2x2.5mm | C12668 | SMT | https://www.lcsc.com/product-detail/C12668.html | 12 pF load is consistent with two 15 pF capacitors plus estimated pin and PCB stray capacitance; verify oscillator margin on prototypes.
SW1 | 1 | C&K | RS-282G05A3-SMRT | Momentary SPST reset switch | C&K RS-282G05A3 SMD; Button_Switch_SMD:SW_SPST_CK_RS282G05A3 | C221930 | SMT | https://www.lcsc.com/product-detail/C221930.html
J1 | 1 | XFCN | PZ254V-11-12P | Single-row male pin header | 1x12, 2.54 mm pitch, vertical THT; Connector_PinHeader_2.54mm:PinHeader_1x12_P2.54mm_Vertical | C2840012 | THT | https://www.lcsc.com/product-detail/C2840012.html | Quote THT assembly separately and confirm pin protrusion suits breadboards.

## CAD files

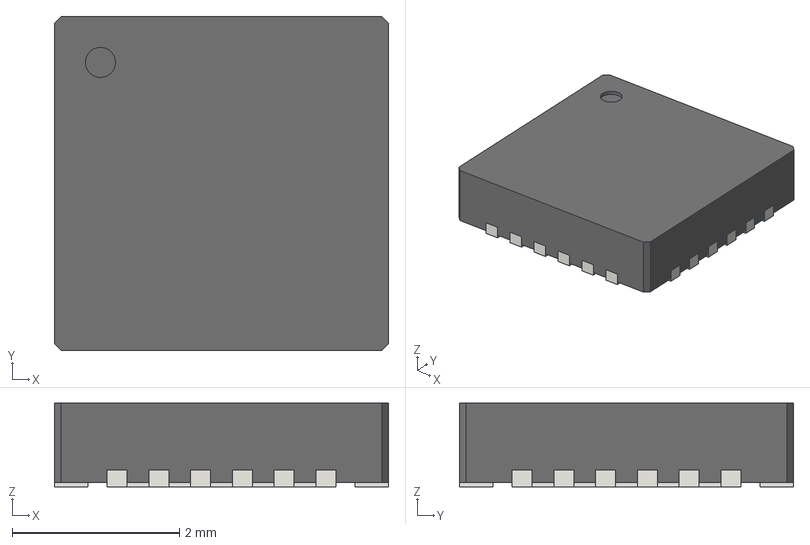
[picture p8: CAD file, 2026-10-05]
hardware/STPM32_Breakout/models/step/STPM32_VQFN24_4x4_EP2.45.step
4.00 x 4.00 x 1.00 mm
molded_body
terminals

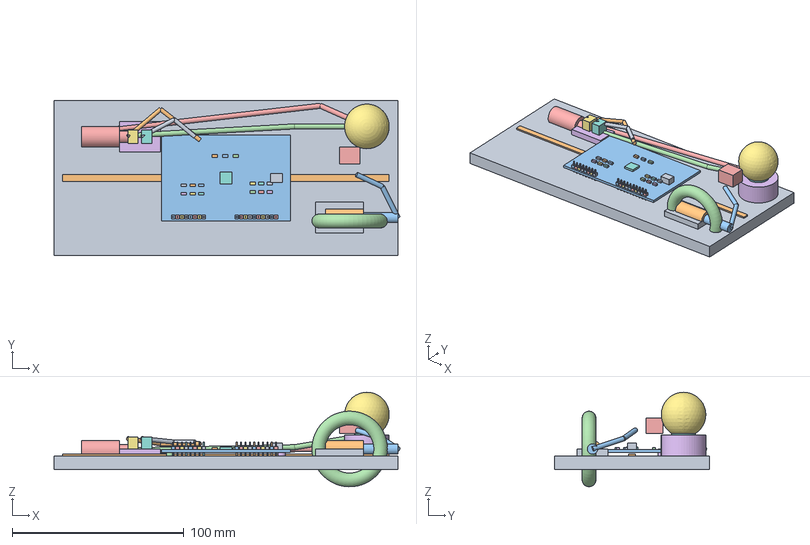
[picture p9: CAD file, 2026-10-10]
hardware/STPM34_Breakout/bench/STPM34_Bench_Setup.FCStd
201.3 x 90.0 x 55.0 mm
Breadboard_Base
Breadboard_Centre_Groove
STPM34_PCB
Board_Standoff_-32.5_-20
Board_Standoff_-32.5_20
Board_Standoff_32.5_-20
Board_Standoff_32.5_20
STPM34_U1
STPM34_Reset
STPM34_J1_Pin_1
STPM34_J1_Body_1
STPM34_J1_Pin_2
STPM34_J1_Body_2
STPM34_J1_Pin_3
STPM34_J1_Body_3
STPM34_J1_Pin_4
STPM34_J1_Body_4
STPM34_J1_Pin_5
STPM34_J1_Body_5
STPM34_J1_Pin_6
STPM34_J1_Body_6
STPM34_J1_Pin_7
STPM34_J1_Body_7
STPM34_J1_Pin_8
STPM34_J1_Body_8
STPM34_J2_Pin_1
STPM34_J2_Body_1
STPM34_J2_Pin_2
STPM34_J2_Body_2
STPM34_J2_Pin_3
STPM34_J2_Body_3
STPM34_J2_Pin_4
STPM34_J2_Body_4
STPM34_J2_Pin_5
STPM34_J2_Body_5
STPM34_J2_Pin_6
STPM34_J2_Body_6
STPM34_J2_Pin_7
STPM34_J2_Body_7
STPM34_J2_Pin_8
STPM34_J2_Body_8
STPM34_J2_Pin_9
STPM34_J2_Body_9
STPM34_J2_Pin_10
STPM34_J2_Body_10
STPM34_Passive_1
STPM34_Passive_2
STPM34_Passive_3
STPM34_Passive_4
STPM34_Passive_5
STPM34_Passive_6
STPM34_Passive_7
STPM34_Passive_8
STPM34_Passive_9
STPM34_Passive_10
STPM34_Passive_11
STPM34_Passive_12
STPM34_Passive_13
STPM34_Passive_14
STPM34_Passive_15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

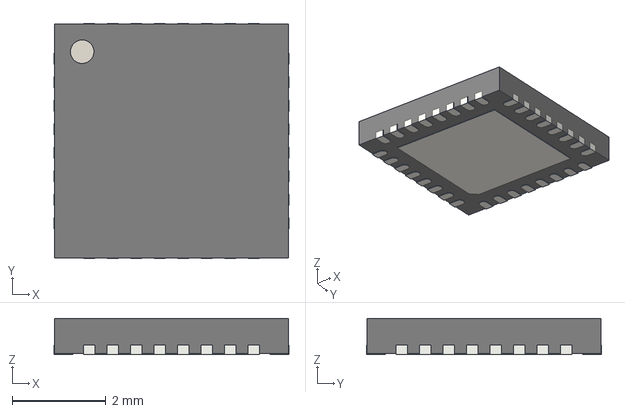
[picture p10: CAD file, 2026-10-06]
hardware/STPM34_Breakout/models/step/QFN-32-1EP_5x5mm_P0.5mm_EP3.45x3.45mm.step
5.00 x 5.00 x 0.77 mm

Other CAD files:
hardware/STPM34_Breakout/bench/STPM34_Bench_Setup.blend

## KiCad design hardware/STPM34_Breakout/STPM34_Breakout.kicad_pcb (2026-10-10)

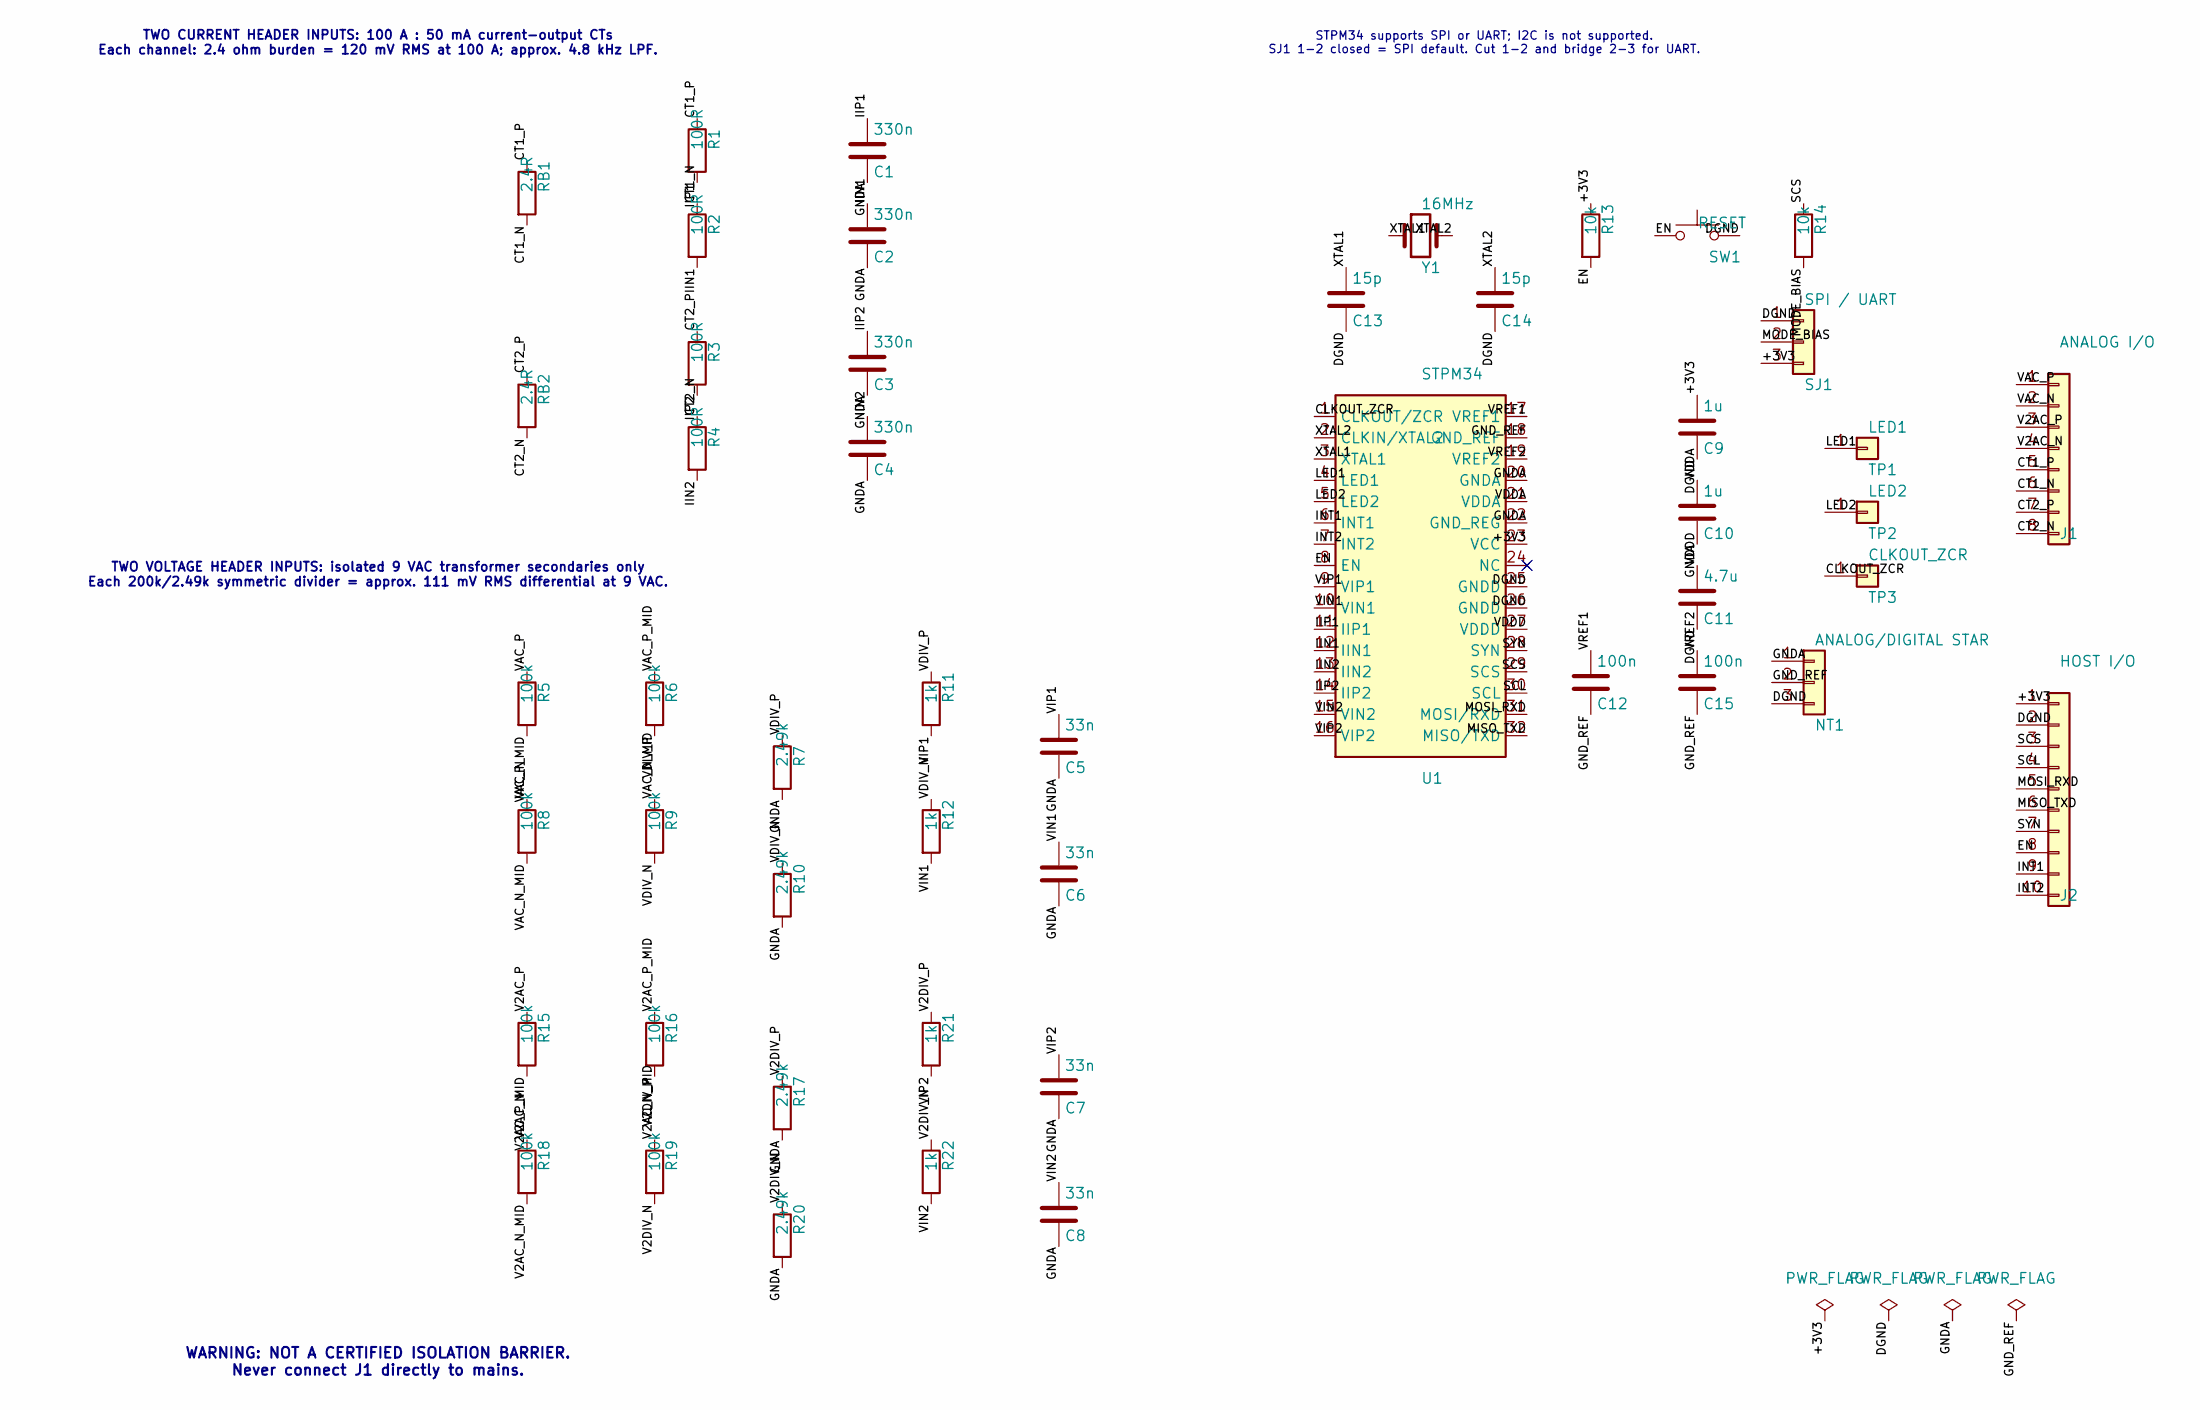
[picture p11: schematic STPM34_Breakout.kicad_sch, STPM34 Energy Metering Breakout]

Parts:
C1, C2, C3, C4: 330n; C_0603_1608Metric; MPN TCC0603X7R334K500CT; LCSC C282682
C5, C6, C7, C8: 33n; C_0603_1608Metric; MPN CL10B333KB8NNNC; LCSC C21117
C9, C10: 1u; C_0805_2012Metric; MPN CL21B105KAFNNNE; LCSC C116352
C11: 4.7u; C_0805_2012Metric; MPN CL21A475KOFNNNG; LCSC C16194928
C12, C15: 100n; C_0603_1608Metric; MPN CL10B104KB8NNNC; LCSC C1591
C13, C14: 15p; C_0603_1608Metric; MPN CL10C150JB8NNNC; LCSC C1644
J1: ANALOG I/O; PinHeader_1x08_P2.54mm_Vertical; MPN PZ254V-11-08P; LCSC C492407
J2: HOST I/O; PinHeader_1x10_P2.54mm_Vertical; MPN PZ254V-11-10P; LCSC C492409
NT1: ANALOG/DIGITAL STAR; NetTie-3_SMD_Pad0.5mm
R1, R2, R3, R4: 100R; R_0603_1608Metric; MPN RC0603FR-07100RL; LCSC C105588
R5, R6, R8, R9, R15, R16, R18, R19: 100k; R_0603_1608Metric; MPN RT0603BRD07100KL; LCSC C122538
R7, R10, R17, R20: 2.49k; R_0603_1608Metric; MPN RT0603BRD072K49L; LCSC C861299
R11, R12, R21, R22: 1k; R_0603_1608Metric; MPN RC0603FR-071KL; LCSC C22548
R13, R14: 10k; R_0603_1608Metric; MPN RC0603FR-0710KL; LCSC C98220
RB1, RB2: 2.4R; R_0603_1608Metric; MPN RC0603FR-072R4L; LCSC C137746
SJ1: SPI / UART; SolderJumper-3_P1.3mm_Bridged12_Pad1.0x1.5mm
SW1: RESET; SW_SPST_CK_RS282G05A3; MPN RS-282G05A3-SMRT; LCSC C221930
TP1: LED1; TestPoint_Pad_D1.5mm
TP2: LED2; TestPoint_Pad_D1.5mm
TP3: CLKOUT_ZCR; TestPoint_Pad_D1.5mm
U1: STPM34; QFN-32-1EP_5x5mm_P0.5mm_EP3.45x3.45mm; MPN STPM34TR; LCSC C129475
Y1: 16MHz; Crystal_SMD_3225-4Pin_3.2x2.5mm; MPN X322516MOB4SI; LCSC C12668

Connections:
+3V3: C9.1, J2.1, R13.1, SJ1.3, U1.23 (VCC)
CLKOUT_ZCR: TP3.1, U1.1 (CLKOUT/ZCR)
CT1_N: J1.6, R2.1, RB1.2
CT1_P: J1.5, R1.1, RB1.1
CT2_N: J1.8, R4.1, RB2.2
CT2_P: J1.7, R3.1, RB2.1
DGND: C9.2, C11.2, C13.2, C14.2, J2.2, NT1.3, SJ1.1, SW1.2, U1.25 (GNDD), U1.26 (GNDD)
EN: J2.8, R13.2, SW1.1, U1.8 (EN)
GNDA: C1.2, C2.2, C3.2, C4.2, C5.2, C6.2, C7.2, C8.2, C10.2, NT1.1, R7.2, R10.2, R17.2, R20.2, U1.20 (GNDA), U1.22 (GND_REG)
GND_REF: C12.2, C15.2, NT1.2, U1.18 (GND_REF)
IIN1: C2.1, R2.2, U1.12 (IIN1)
IIN2: C4.1, R4.2, U1.13 (IIN2)
IIP1: C1.1, R1.2, U1.11 (IIP1)
IIP2: C3.1, R3.2, U1.14 (IIP2)
INT1: J2.9, U1.6 (INT1)
INT2: J2.10, U1.7 (INT2)
LED1: TP1.1, U1.4 (LED1)
LED2: TP2.1, U1.5 (LED2)
MISO_TXD: J2.6, U1.32 (MISO/TXD)
MODE_BIAS: R14.2, SJ1.2
MOSI_RXD: J2.5, U1.31 (MOSI/RXD)
SCL: J2.4, U1.30 (SCL)
SCS: J2.3, R14.1, U1.29 (SCS)
SYN: J2.7, U1.28 (SYN)
V2AC_N: J1.4, R18.1
V2AC_N_MID: R18.2, R19.1
V2AC_P: J1.3, R15.1
V2AC_P_MID: R15.2, R16.1
V2DIV_N: R19.2, R20.1, R22.1
V2DIV_P: R16.2, R17.1, R21.1
VAC_N: J1.2, R8.1
VAC_N_MID: R8.2, R9.1
VAC_P: J1.1, R5.1
VAC_P_MID: R5.2, R6.1
VDDA: C10.1, U1.21 (VDDA)
VDDD: C11.1, U1.27 (VDDD)
VDIV_N: R9.2, R10.1, R12.1
VDIV_P: R6.2, R7.1, R11.1
VIN1: C6.1, R12.2, U1.10 (VIN1)
VIN2: C8.1, R22.2, U1.15 (VIN2)
VIP1: C5.1, R11.2, U1.9 (VIP1)
VIP2: C7.1, R21.2, U1.16 (VIP2)
VREF1: C12.1, U1.17 (VREF1)
VREF2: C15.1, U1.19 (VREF2)
XTAL1: C13.1, U1.3 (XTAL1), Y1.1
XTAL2: C14.1, U1.2 (CLKIN/XTAL2), Y1.2

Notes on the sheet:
TWO CURRENT HEADER INPUTS: 100 A : 50 mA current-output CTs Each channel: 2.4 ohm burden = 120 mV RMS at 100 A; approx. 4.8 kHz LPF.
TWO VOLTAGE HEADER INPUTS: isolated 9 VAC transformer secondaries only Each 200k/2.49k symmetric divider = approx. 111 mV RMS differential at 9 VAC.
WARNING: NOT A CERTIFIED ISOLATION BARRIER. Never connect J1 directly to mains.
STPM34 supports SPI or UART; I2C is not supported. SJ1 1-2 closed = SPI default. Cut 1-2 and bridge 2-3 for UART.

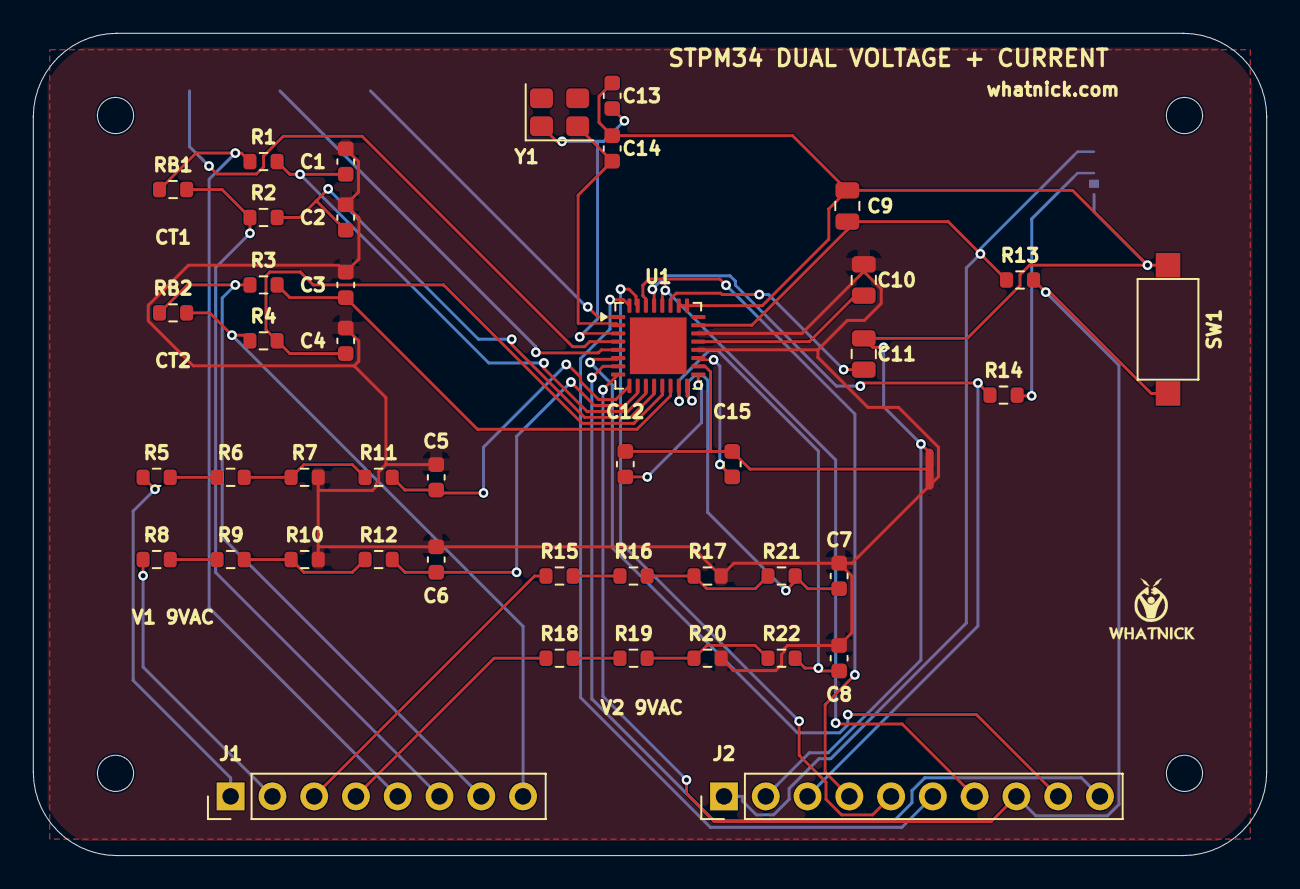
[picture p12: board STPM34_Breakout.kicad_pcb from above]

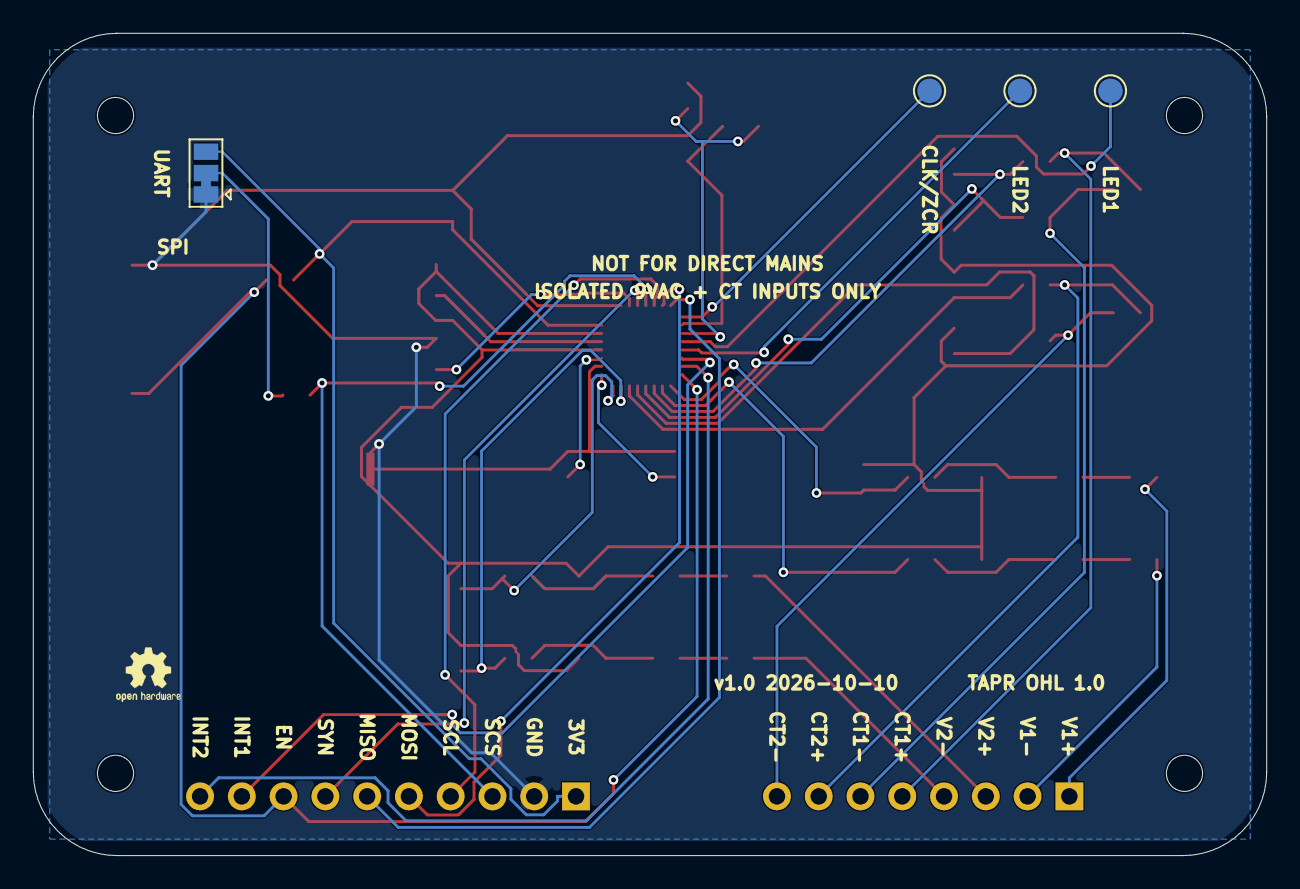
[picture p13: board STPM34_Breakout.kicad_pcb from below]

Board: 2 copper layers, 75.0 x 50.0 mm, 55 parts (5 on the bottom side), 46 nets.

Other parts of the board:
H1, H2, H3, H4: MountingHole_2.2mm_M2
LOGO_OSHW: OSHW_Logo
LOGO_W: Whatnick_Logo

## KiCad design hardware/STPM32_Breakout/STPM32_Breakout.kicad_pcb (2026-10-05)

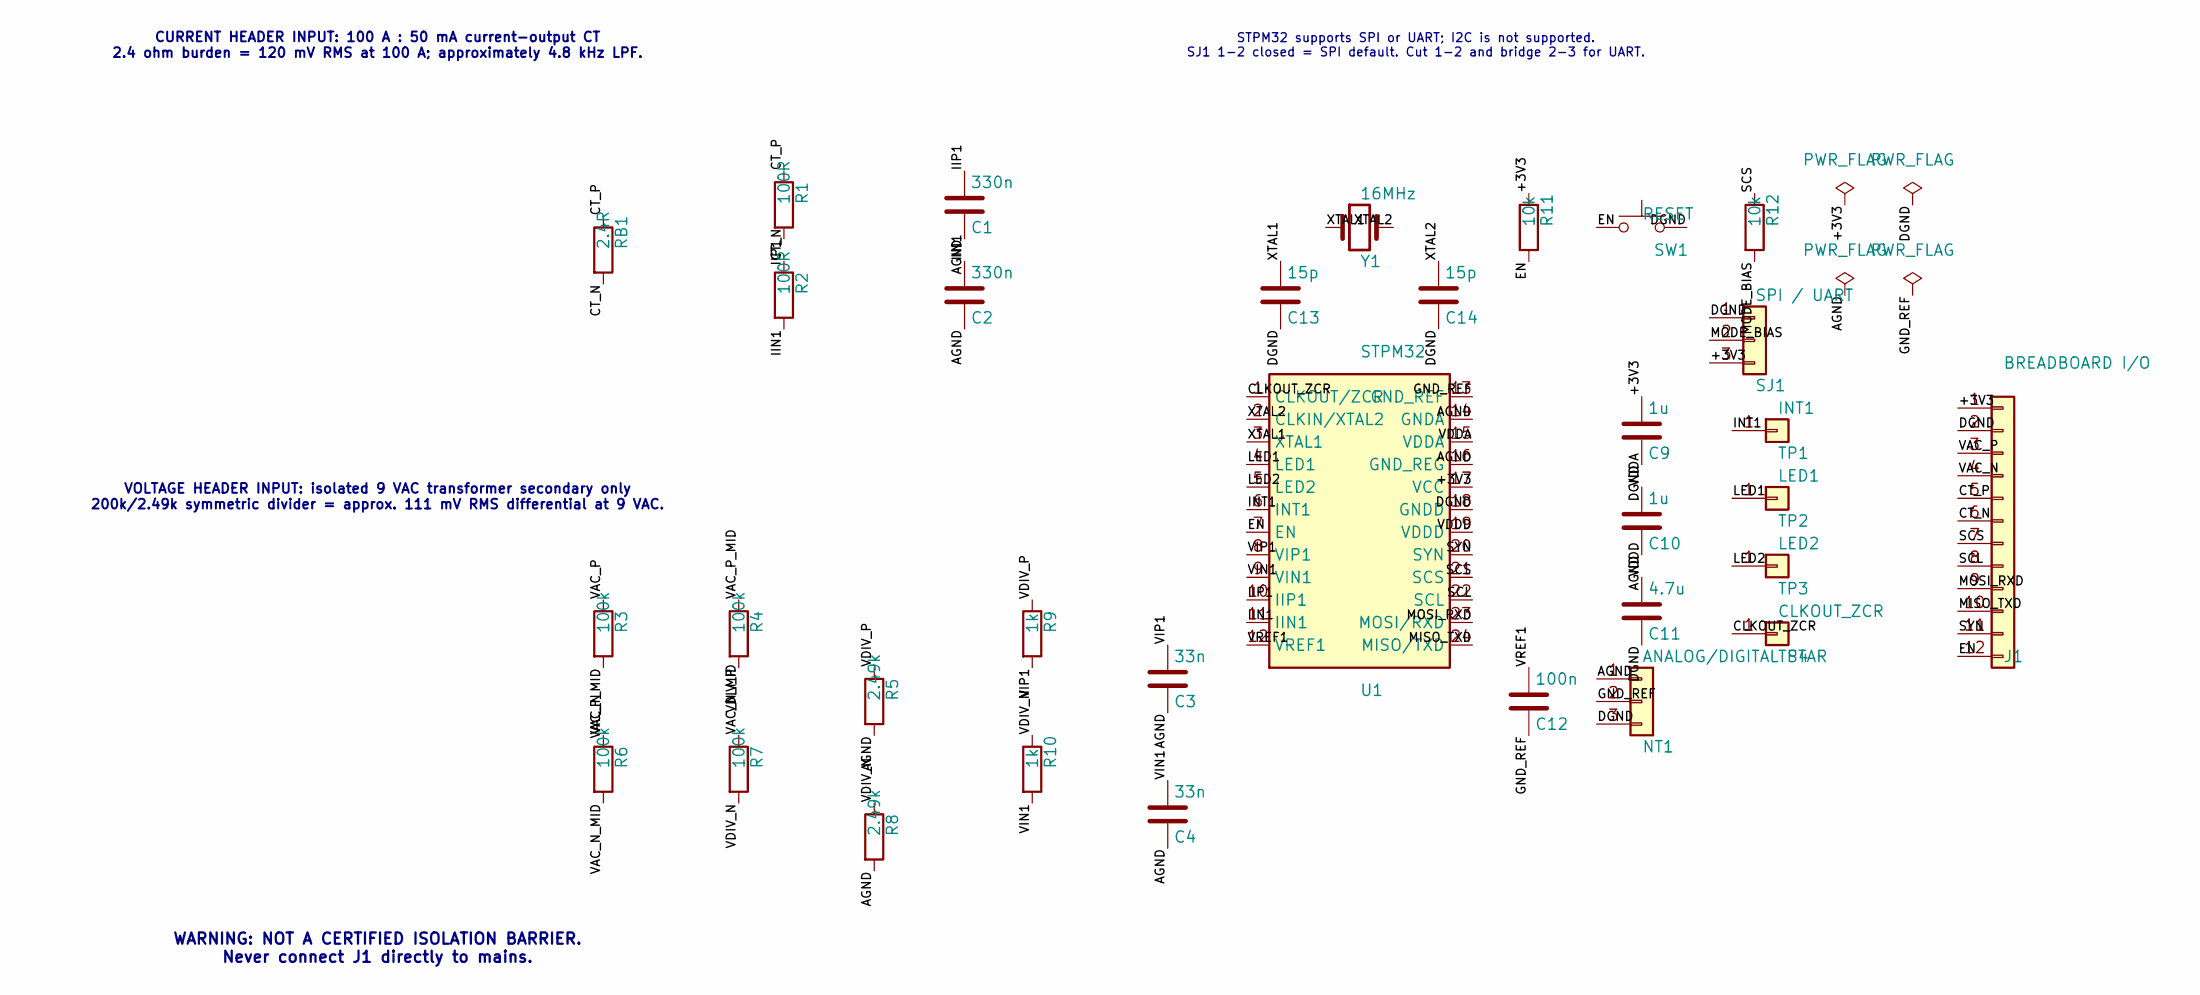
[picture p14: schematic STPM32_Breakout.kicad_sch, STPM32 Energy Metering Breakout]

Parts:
C1, C2: 330n; C_0603_1608Metric; MPN TCC0603X7R334K500CT; LCSC C282682
C3, C4: 33n; C_0603_1608Metric; MPN CL10B333KB8NNNC; LCSC C21117
C9, C10: 1u; C_0805_2012Metric; MPN CL21B105KAFNNNE; LCSC C116352
C11: 4.7u; C_0805_2012Metric; MPN CL21A475KOFNNNG; LCSC C16194928
C12: 100n; C_0603_1608Metric; MPN CL10B104KB8NNNC; LCSC C1591
C13, C14: 15p; C_0603_1608Metric; MPN CL10C150JB8NNNC; LCSC C1644
J1: BREADBOARD I/O; PinHeader_1x12_P2.54mm_Vertical; MPN PZ254V-11-12P; LCSC C2840012
NT1: ANALOG/DIGITAL STAR; NetTie-3_SMD_Pad0.5mm
R1, R2: 100R; R_0603_1608Metric; MPN RC0603FR-07100RL; LCSC C105588
R3, R4, R6, R7: 100k; R_0603_1608Metric; MPN RT0603BRD07100KL; LCSC C122538
R5, R8: 2.49k; R_0603_1608Metric; MPN RT0603BRD072K49L; LCSC C861299
R9, R10: 1k; R_0603_1608Metric; MPN RC0603FR-071KL; LCSC C22548
R11, R12: 10k; R_0603_1608Metric; MPN RC0603FR-0710KL; LCSC C98220
RB1: 2.4R; R_0603_1608Metric; MPN RC0603FR-072R4L; LCSC C137746
SJ1: SPI / UART; SolderJumper-3_P1.3mm_Bridged12_Pad1.0x1.5mm
SW1: RESET; SW_SPST_CK_RS282G05A3; MPN RS-282G05A3-SMRT; LCSC C221930
TP1: INT1; TestPoint_Pad_D1.5mm
TP2: LED1; TestPoint_Pad_D1.5mm
TP3: LED2; TestPoint_Pad_D1.5mm
TP4: CLKOUT_ZCR; TestPoint_Pad_D1.5mm
U1: STPM32; VQFN-24-1EP_4x4mm_P0.5mm_EP2.45x2.45mm; MPN STPM32TR; LCSC C128380
Y1: 16MHz; Crystal_SMD_3225-4Pin_3.2x2.5mm; MPN X322516MOB4SI; LCSC C12668

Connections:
+3V3: C9.1, J1.1, R11.1, SJ1.3, U1.17 (VCC)
AGND: C1.2, C2.2, C3.2, C4.2, C10.2, NT1.1, R5.2, R8.2, U1.14 (GNDA), U1.16 (GND_REG)
CLKOUT_ZCR: TP4.1, U1.1 (CLKOUT/ZCR)
CT_N: J1.6, R2.1, RB1.2
CT_P: J1.5, R1.1, RB1.1
DGND: C9.2, C11.2, C13.2, C14.2, J1.2, NT1.3, SJ1.1, SW1.2, U1.18 (GNDD)
EN: J1.12, R11.2, SW1.1, U1.7 (EN)
GND_REF: C12.2, NT1.2, U1.13 (GND_REF)
IIN1: C2.1, R2.2, U1.11 (IIN1)
IIP1: C1.1, R1.2, U1.10 (IIP1)
INT1: TP1.1, U1.6 (INT1)
LED1: TP2.1, U1.4 (LED1)
LED2: TP3.1, U1.5 (LED2)
MISO_TXD: J1.10, U1.24 (MISO/TXD)
MODE_BIAS: R12.2, SJ1.2
MOSI_RXD: J1.9, U1.23 (MOSI/RXD)
SCL: J1.8, U1.22 (SCL)
SCS: J1.7, R12.1, U1.21 (SCS)
SYN: J1.11, U1.20 (SYN)
VAC_N: J1.4, R6.1
VAC_N_MID: R6.2, R7.1
VAC_P: J1.3, R3.1
VAC_P_MID: R3.2, R4.1
VDDA: C10.1, U1.15 (VDDA)
VDDD: C11.1, U1.19 (VDDD)
VDIV_N: R7.2, R8.1, R10.1
VDIV_P: R4.2, R5.1, R9.1
VIN1: C4.1, R10.2, U1.9 (VIN1)
VIP1: C3.1, R9.2, U1.8 (VIP1)
VREF1: C12.1, U1.12 (VREF1)
XTAL1: C13.1, U1.3 (XTAL1), Y1.1
XTAL2: C14.1, U1.2 (CLKIN/XTAL2), Y1.2

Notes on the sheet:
CURRENT HEADER INPUT: 100 A : 50 mA current-output CT 2.4 ohm burden = 120 mV RMS at 100 A; approximately 4.8 kHz LPF.
VOLTAGE HEADER INPUT: isolated 9 VAC transformer secondary only 200k/2.49k symmetric divider = approx. 111 mV RMS differential at 9 VAC.
WARNING: NOT A CERTIFIED ISOLATION BARRIER. Never connect J1 directly to mains.
STPM32 supports SPI or UART; I2C is not supported. SJ1 1-2 closed = SPI default. Cut 1-2 and bridge 2-3 for UART.

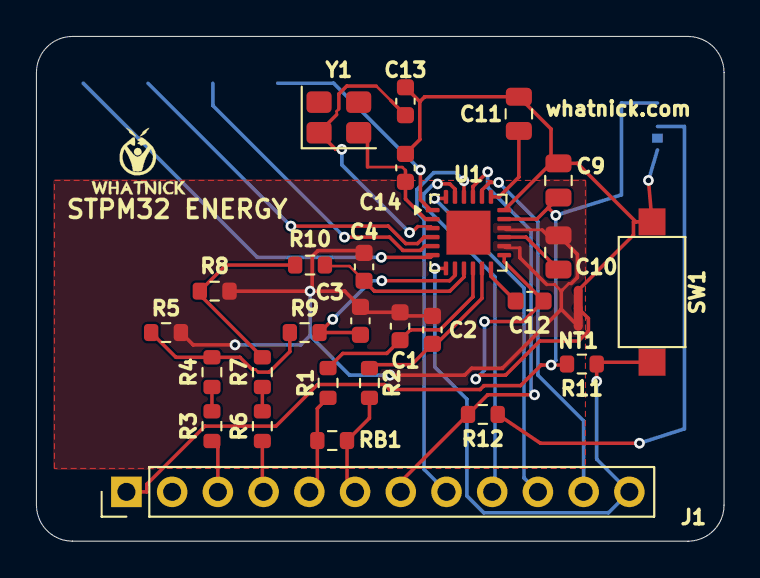
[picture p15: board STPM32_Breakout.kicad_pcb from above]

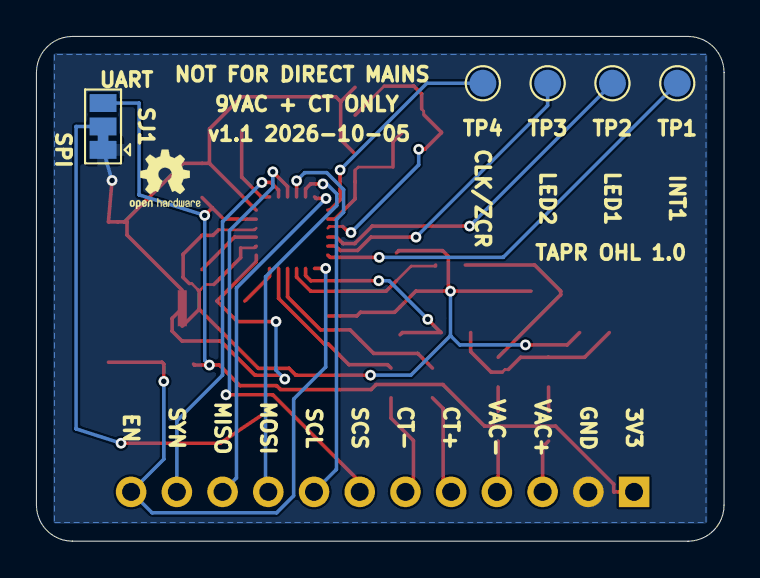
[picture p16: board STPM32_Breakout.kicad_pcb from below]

Board: 2 copper layers, 38.2 x 28.0 mm, 35 parts (6 on the bottom side), 32 nets.

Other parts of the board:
LOGO_OSHW: OSHW_Logo
LOGO_W: Whatnick_Logo

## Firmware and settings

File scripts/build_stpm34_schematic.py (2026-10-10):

#!/usr/bin/env python3
"""Build the STPM34 breakout schematic with dual isolated voltage and CT inputs."""

from pathlib import Path

import kicad_sch_api as ksa

from stpm34_parts import apply_part_metadata


ROOT = Path(__file__).resolve().parents[1]
SYMBOL_LIBRARY = ROOT / "symbols" / "STPM3x.kicad_sym"
OUTPUT = ROOT / "hardware" / "STPM34_Breakout" / "STPM34_Breakout.kicad_sch"

R0603 = "Resistor_SMD:R_0603_1608Metric"
C0603 = "Capacitor_SMD:C_0603_1608Metric"
C0805 = "Capacitor_SMD:C_0805_2012Metric"


def main() -> None:
    cache = ksa.get_symbol_cache()
    cache.add_library_path(SYMBOL_LIBRARY)

    schematic = ksa.create_schematic("STPM34_Breakout")
    schematic.set_title_block(
        title="STPM34 Energy Metering Breakout",
        rev="A",
        company="Whatnick",
        comments={
            1: "Two isolated 9 VAC inputs and two 100 A:50 mA CT inputs",
            2: "TAPR Open Hardware License 1.0",
        },
    )

    def add(
        lib_id: str,
        reference: str,
        value: str,
        position: tuple[float, float],
        footprint: str = "",
        rotation: float = 0.0,
    ):
        return schematic.components.add(
            lib_id,
            reference,
            value,
            position=position,
            footprint=footprint,
            rotation=rotation,
        )

    def net(reference: str, pin: str, name: str) -> None:
        schematic.add_label(name, pin=(reference, pin), size=1.0)

    def two_pin(
        reference: str,
        value: str,
        position: tuple[float, float],
        pin1_net: str,
        pin2_net: str,
        *,
        capacitor: bool = False,
        footprint: str | None = None,
        rotation: float = 0.0,
    ) -> None:
        add(
            "Device:C" if capacitor else "Device:R",
            reference,
            value,
            position,
            footprint or (C0603 if capacitor else R0603),
            rotation,
        )
        net(reference, "1", pin1_net)
        net(reference, "2", pin2_net)

    u1 = add(
        "STPM3x:STPM34",
        "U1",
        "STPM34",
        (149.86, 91.44),
        "Package_DFN_QFN:QFN-32-1EP_5x5mm_P0.5mm_EP3.45x3.45mm",
    )
    u1_nets = {
        "1": "CLKOUT_ZCR",
        "2": "XTAL2",
        "3": "XTAL1",
        "4": "LED1",
        "5": "LED2",
        "6": "INT1",
        "7": "INT2",
        "8": "EN",
        "9": "VIP1",
        "10": "VIN1",
        "11": "IIP1",
        "12": "IIN1",
        "13": "IIN2",
        "14": "IIP2",
        "15": "VIN2",
        "16": "VIP2",
        "17": "VREF1",
        "18": "GND_REF",
        "19": "VREF2",
        "20": "GNDA",
        "21": "VDDA",
        "22": "GNDA",
        "23": "+3V3",
        "25": "DGND",
        "26": "DGND",
        "27": "VDDD",
        "28": "SYN",
        "29": "SCS",
        "30": "SCL",
        "31": "MOSI_RXD",
        "32": "MISO_TXD",
    }
    for pin, name in u1_nets.items():
        net("U1", pin, name)
    schematic.no_connects.add((162.56, 90.17))

    two_pin("C9", "1u", (182.88, 73.66), "+3V3", "DGND", capacitor=True, footprint=C0805)
    two_pin("C10", "1u", (182.88, 83.82), "VDDA", "GNDA", capacitor=True, footprint=C0805)
    two_pin("C11", "4.7u", (182.88, 93.98), "VDDD", "DGND", capacitor=True, footprint=C0805)
    two_pin("C12", "100n", (170.18, 104.14), "VREF1", "GND_REF", capacitor=True)
    two_pin("C15", "100n", (182.88, 104.14), "VREF2", "GND_REF", capacitor=True)

    add(
        "Connector_Generic:Conn_01x03",
        "NT1",
        "ANALOG/DIGITAL STAR",
        (196.85, 104.14),
        "NetTie:NetTie-3_SMD_Pad0.5mm",
    )
    net("NT1", "1", "GNDA")
    net("NT1", "2", "GND_REF")
    net("NT1", "3", "DGND")

    add(
        "Device:Crystal",
        "Y1",
        "16MHz",
        (149.86, 50.80),
        "Crystal:Crystal_SMD_3225-4Pin_3.2x2.5mm",
    )
    net("Y1", "1", "XTAL1")
    net("Y1", "2", "XTAL2")
    two_pin("C13", "15p", (140.97, 58.42), "XTAL1", "DGND", capacitor=True)
    two_pin("C14", "15p", (158.75, 58.42), "XTAL2", "DGND", capacitor=True)

    two_pin("R13", "10k", (170.18, 50.80), "+3V3", "EN")
    add(
        "Switch:SW_Push",
        "SW1",
        "RESET",
        (182.88, 50.80),
        "Button_Switch_SMD:SW_SPST_CK_RS282G05A3",
    )
    net("SW1", "1", "EN")
    net("SW1", "2", "DGND")
    two_pin("R14", "10k", (195.58, 50.80), "SCS", "MODE_BIAS")
    add(
        "Connector_Generic:Conn_01x03",
        "SJ1",
        "SPI / UART",
        (195.58, 63.50),
        "Jumper:SolderJumper-3_P1.3mm_Bridged12_Pad1.0x1.5mm",
    )
    net("SJ1", "1", "DGND")
    net("SJ1", "2", "MODE_BIAS")
    net("SJ1", "3", "+3V3")

    two_pin("RB1", "2.4R", (43.18, 45.72), "CT1_P", "CT1_N")
    two_pin("R1", "100R", (63.50, 40.64), "CT1_P", "IIP1")
    two_pin("R2", "100R", (63.50, 50.80), "CT1_N", "IIN1")
    two_pin("C1", "330n", (83.82, 40.64), "IIP1", "GNDA", capacitor=True)
    two_pin("C2", "330n", (83.82, 50.80), "IIN1", "GNDA", capacitor=True)

    two_pin("RB2", "2.4R", (43.18, 71.12), "CT2_P", "CT2_N")
    two_pin("R3", "100R", (63.50, 66.04), "CT2_P", "IIP2")
    two_pin("R4", "100R", (63.50, 76.20), "CT2_N", "IIN2")
    two_pin("C3", "330n", (83.82, 66.04), "IIP2", "GNDA", capacitor=True)
    two_pin("C4", "330n", (83.82, 76.20), "IIN2", "GNDA", capacitor=True)

    two_pin("R5", "100k", (43.18, 106.68), "VAC_P", "VAC_P_MID")
    two_pin("R6", "100k", (58.42, 106.68), "VAC_P_MID", "VDIV_P")
    two_pin("R7", "2.49k", (73.66, 114.30), "VDIV_P", "GNDA")
    two_pin("R8", "100k", (43.18, 121.92), "VAC_N", "VAC_N_MID")
    two_pin("R9", "100k", (58.42, 121.92), "VAC_N_MID", "VDIV_N")
    two_pin("R10", "2.49k", (73.66, 129.54), "VDIV_N", "GNDA")
    two_pin("R11", "1k", (91.44, 106.68), "VDIV_P", "VIP1")
    two_pin("R12", "1k", (91.44, 121.92), "VDIV_N", "VIN1")
    two_pin("C5", "33n", (106.68, 111.76), "VIP1", "GNDA", capacitor=True)
    two_pin("C6", "33n", (106.68, 127.00), "VIN1", "GNDA", capacitor=True)

    two_pin("R15", "100k", (43.18, 147.32), "V2AC_P", "V2AC_P_MID")
    two_pin("R16", "100k", (58.42, 147.32), "V2AC_P_MID", "V2DIV_P")
    two_pin("R17", "2.49k", (73.66, 154.94), "V2DIV_P", "GNDA")
    two_pin("R18", "100k", (43.18, 162.56), "V2AC_N", "V2AC_N_MID")
    two_pin("R19", "100k", (58.42, 162.56), "V2AC_N_MID", "V2DIV_N")
    two_pin("R20", "2.49k", (73.66, 170.18), "V2DIV_N", "GNDA")
    two_pin("R21", "1k", (91.44, 147.32), "V2DIV_P", "VIP2")
    two_pin("R22", "1k", (91.44, 162.56), "V2DIV_N", "VIN2")
    two_pin("C7", "33n", (106.68, 152.40), "VIP2", "GNDA", capacitor=True)
    two_pin("C8", "33n", (106.68, 167.64), "VIN2", "GNDA", capacitor=True)
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

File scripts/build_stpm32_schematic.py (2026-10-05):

#!/usr/bin/env python3
"""Build the STPM32 breakout schematic with isolated voltage and CT inputs."""

from pathlib import Path

import kicad_sch_api as ksa

from stpm32_parts import apply_part_metadata


ROOT = Path(__file__).resolve().parents[1]
SYMBOL_LIBRARY = ROOT / "symbols" / "STPM3x.kicad_sym"
OUTPUT = (
    ROOT
    / "hardware"
    / "STPM32_Breakout"
    / "STPM32_Breakout.kicad_sch"
)

R0603 = "Resistor_SMD:R_0603_1608Metric"
C0603 = "Capacitor_SMD:C_0603_1608Metric"
C0805 = "Capacitor_SMD:C_0805_2012Metric"


def main() -> None:
    cache = ksa.get_symbol_cache()
    cache.add_library_path(SYMBOL_LIBRARY)

    schematic = ksa.create_schematic("STPM32_Breakout")
    schematic.set_title_block(
        title="STPM32 Energy Metering Breakout",
        rev="B",
        company="Whatnick",
        comments={
            1: "Isolated 9 VAC voltage input and 100 A:50 mA current-output CT",
            2: "TAPR Open Hardware License 1.0",
        },
    )

    def add(
        lib_id: str,
        reference: str,
        value: str,
        position: tuple[float, float],
        footprint: str = "",
        rotation: float = 0.0,
    ):
        return schematic.components.add(
            lib_id,
            reference,
            value,
            position=position,
            footprint=footprint,
            rotation=rotation,
        )

    def net(reference: str, pin: str, name: str) -> None:
        schematic.add_label(name, pin=(reference, pin), size=1.0)

    def two_pin(
        reference: str,
        value: str,
        position: tuple[float, float],
        pin1_net: str,
        pin2_net: str,
        *,
        capacitor: bool = False,
        footprint: str | None = None,
        rotation: float = 0.0,
    ) -> None:
        add(
            "Device:C" if capacitor else "Device:R",
            reference,
            value,
            position,
            footprint or (C0603 if capacitor else R0603),
            rotation,
        )
        net(reference, "1", pin1_net)
        net(reference, "2", pin2_net)

    # Metering IC and all mandatory support circuitry.
    add(
        "STPM3x:STPM32",
        "U1",
        "STPM32",
        (140.97, 88.90),
        "Package_DFN_QFN:VQFN-24-1EP_4x4mm_P0.5mm_EP2.45x2.45mm",
    )
    u1_nets = {
        "1": "CLKOUT_ZCR",
        "2": "XTAL2",
        "3": "XTAL1",
        "4": "LED1",
        "5": "LED2",
        "6": "INT1",
        "7": "EN",
        "8": "VIP1",
        "9": "VIN1",
        "10": "IIP1",
        "11": "IIN1",
        "12": "VREF1",
        "13": "GND_REF",
        "14": "AGND",
        "15": "VDDA",
        "16": "AGND",
        "17": "+3V3",
        "18": "DGND",
        "19": "VDDD",
        "20": "SYN",
        "21": "SCS",
        "22": "SCL",
        "23": "MOSI_RXD",
        "24": "MISO_TXD",
    }
    for pin, name in u1_nets.items():
        net("U1", pin, name)

    two_pin("C9", "1u", (172.72, 78.74), "+3V3", "DGND", capacitor=True, footprint=C0805)
    two_pin("C10", "1u", (172.72, 88.90), "VDDA", "AGND", capacitor=True, footprint=C0805)
    two_pin("C11", "4.7u", (172.72, 99.06), "VDDD", "DGND", capacitor=True, footprint=C0805)
    two_pin("C12", "100n", (160.02, 109.22), "VREF1", "GND_REF", capacitor=True)

    add(
        "Connector_Generic:Conn_01x03",
        "NT1",
        "ANALOG/DIGITAL STAR",
        (172.72, 109.22),
        "NetTie:NetTie-3_SMD_Pad0.5mm",
    )
    net("NT1", "1", "AGND")
    net("NT1", "2", "GND_REF")
    net("NT1", "3", "DGND")

    # 16 MHz crystal oscillator.
    add(
        "Device:Crystal",
        "Y1",
        "16MHz",
        (140.97, 55.88),
        "Crystal:Crystal_SMD_3225-4Pin_3.2x2.5mm",
    )
    net("Y1", "1", "XTAL1")
    net("Y1", "2", "XTAL2")
    two_pin("C13", "15p", (132.08, 63.50), "XTAL1", "DGND", capacitor=True)
    two_pin("C14", "15p", (149.86, 63.50), "XTAL2", "DGND", capacitor=True)

    # Enable and interface-mode defaults: enabled and SPI unless reconfigured.
    two_pin("R11", "10k", (160.02, 55.88), "+3V3", "EN")
    add(
        "Switch:SW_Push",
        "SW1",
        "RESET",
        (172.72, 55.88),
        "Button_Switch_SMD:SW_SPST_CK_RS282G05A3",
    )
    net("SW1", "1", "EN")
    net("SW1", "2", "DGND")
    two_pin("R12", "10k", (185.42, 55.88), "SCS", "MODE_BIAS")
    add(
        "Connector_Generic:Conn_01x03",
        "SJ1",
        "SPI / UART",
        (185.42, 68.58),
        "Jumper:SolderJumper-3_P1.3mm_Bridged12_Pad1.0x1.5mm",
    )
    net("SJ1", "1", "DGND")
    net("SJ1", "2", "MODE_BIAS")
    net("SJ1", "3", "+3V3")

    # Current channel: header input, 2.4 ohm differential burden and LPF.
    two_pin("RB1", "2.4R", (55.88, 58.42), "CT_P", "CT_N")
    two_pin("R1", "100R", (76.20, 53.34), "CT_P", "IIP1")
    two_pin("R2", "100R", (76.20, 63.50), "CT_N", "IIN1")
    two_pin("C1", "330n", (96.52, 53.34), "IIP1", "AGND", capacitor=True)
    two_pin("C2", "330n", (96.52, 63.50), "IIN1", "AGND", capacitor=True)

    # Voltage channel: isolated 9 VAC source, symmetric 200k/2.49k divider and LPF.
    two_pin("R3", "100k", (55.88, 101.60), "VAC_P", "VAC_P_MID")
    two_pin("R4", "100k", (71.12, 101.60), "VAC_P_MID", "VDIV_P")
    two_pin("R5", "2.49k", (86.36, 109.22), "VDIV_P", "AGND")
    two_pin("R6", "100k", (55.88, 116.84), "VAC_N", "VAC_N_MID")
    two_pin("R7", "100k", (71.12, 116.84), "VAC_N_MID", "VDIV_N")
    two_pin("R8", "2.49k", (86.36, 124.46), "VDIV_N", "AGND")
    two_pin("R9", "1k", (104.14, 101.60), "VDIV_P", "VIP1")
    two_pin("R10", "1k", (104.14, 116.84), "VDIV_N", "VIN1")
    two_pin("C3", "33n", (119.38, 106.68), "VIP1", "AGND", capacitor=True)
    two_pin("C4", "33n", (119.38, 121.92), "VIN1", "AGND", capacitor=True)

    # Single breadboard I/O header. VDDD and VDDA remain local regulator outputs.
    add(
        "Connector_Generic:Conn_01x12",
        "J1",
        "BREADBOARD I/O",
        (213.36, 88.90),
        "Connector_PinHeader_2.54mm:PinHeader_1x12_P2.54mm_Vertical",
    )
    header_nets = {
        "1": "+3V3",
        "2": "DGND",
        "3": "VAC_P",
        "4": "VAC_N",
        "5": "CT_P",
        "6": "CT_N",
        "7": "SCS",
        "8": "SCL",
        "9": "MOSI_RXD",
        "10": "MISO_TXD",
        "11": "SYN",
        "12": "EN",
    }
    for pin, name in header_nets.items():
        net("J1", pin, name)

    for index, (name, signal) in enumerate(
        (
            ("TP1", "INT1"),
            ("TP2", "LED1"),
            ("TP3", "LED2"),
            ("TP4", "CLKOUT_ZCR"),
        )
    ):
        add(
            "Connector_Generic:Conn_01x01",
            name,
            signal,
            (187.96, 78.74 + index * 7.62),
            "TestPoint:TestPoint_Pad_D1.5mm",
        )
        net(name, "1", signal)
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

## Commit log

2026-10-04 Scaffold STPM3x breakout family
    Add KiCad 10 projects for STPM32, STPM33, and STPM34 with verified project-local symbols, shared mechanics, design requirements, and validation tooling.
    [STPM32_Breakout.kicad_pcb, STPM32_Breakout.kicad_sch, STPM33_Breakout.kicad_pcb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]
2026-10-04 Refocus README on metering ecosystem
    Describe the STPM3x board family, its place among Whatnick energy-monitor platforms, and the planned shared driver ecosystem while moving PCB process details out of the landing page.
2026-10-04 Complete compact STPM32 breakout
    Implement the isolated 9 VAC and current-output CT front end, compact breadboard PCB, routed ground planes, validation scripts, and design documentation.
    [STPM32_Breakout.kicad_pcb, STPM32_Breakout.kicad_sch]
2026-10-05 Add production STPM32 silkscreen
    Mark fitted components and signals, add project-local Whatnick and OSHW artwork, and include release and safety identifiers through a reproducible KiCad script.
    [STPM32_Breakout.kicad_pcb]
2026-10-05 Normalize scaffold silkscreen markers
    Hide drill-only references and standardize fitted component references across the STPM33 and STPM34 scaffold boards and generator.
    [STPM33_Breakout.kicad_pcb, STPM34_Breakout.kicad_pcb]
2026-10-05 Add Elecrow BOM for STPM32
    [STPM32_Breakout.kicad_pcb, STPM32_Breakout.kicad_sch, STPM32_Breakout_Elecrow_BOM.csv]
2026-10-05 Add STPM32 QFN model and renders
    [STPM32_Breakout.kicad_pcb, STPM32_VQFN24_4x4_EP2.45.step]
2026-10-05 Refine STPM32 silkscreen placement
    [STPM32_Breakout.kicad_pcb]
2026-10-05 Fine tune STPM32 rear silkscreen
    [STPM32_Breakout.kicad_pcb]
2026-10-05 Add STPM32 SPI UART mode selector
    [STPM32_Breakout.kicad_pcb, STPM32_Breakout.kicad_sch]
2026-10-05 Add STPM32 Gerber fabrication package
    [STPM32_Breakout-B_Cu.gbr, STPM32_Breakout-B_Mask.gbr, STPM32_Breakout-B_Silkscreen.gbr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]
2026-10-05 Include STPM32 position files in fabrication ZIP
    [STPM32_Breakout-B_Cu.gbr, STPM32_Breakout-B_Mask.gbr, STPM32_Breakout-B_Silkscreen.gbr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]
2026-10-06 Build production STPM33 breakout
    Implement the dual-current isolated-voltage schematic, routed PCB, sourcing metadata, project-local assets, renders, and ERC/DRC-gated Elecrow fabrication package. Document the SPI/UART selector and 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
    [QFN-32-1EP_5x5mm_P0.5mm_EP3.45x3.45mm.step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]
2026-10-06 Normalize STPM33 STEP model
    Remove trailing whitespace from the project-local KiCad package model.
    [QFN-32-1EP_5x5mm_P0.5mm_EP3.45x3.45mm.step]
2026-10-06 Hide STPM33 net-tie reference
    Remove the floating NT1 front-silkscreen label, document that NT1 is a non-fitted copper net tie, and refresh the validated renders and fabrication package.
    [STPM33_Breakout-B_Cu.gbr, STPM33_Breakout-B_Mask.gbr, STPM33_Breakout-B_Silkscreen.gbr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]
2026-10-07 Correct STPM33 selector labels
    Place SPI on the SJ1 pad 1-2 DGND end and UART on the pad 2-3 +3V3 end, then refresh the validated renders and fabrication package.
    [STPM33_Breakout-B_Cu.gbr, STPM33_Breakout-B_Mask.gbr, STPM33_Breakout-B_Silkscreen.gbr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]
2026-10-10 Build production STPM34 breakout
    Implement the dual-voltage dual-current schematic, routed PCB, sourcing metadata, project-local assets, renders, and ERC/DRC-gated Elecrow fabrication package.
    [QFN-32-1EP_5x5mm_P0.5mm_EP3.45x3.45mm.step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]
2026-10-10 Add STPM34 isolated bench render
    Create reproducible FreeCAD and Blender scene assets for an isolated 9 VAC lamp and YHDC CT demonstration, document safety and regeneration, and refresh the validated Elecrow fabrication package.
    [STPM34_Bench_Setup.FCStd, STPM34_Bench_Setup.blend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]

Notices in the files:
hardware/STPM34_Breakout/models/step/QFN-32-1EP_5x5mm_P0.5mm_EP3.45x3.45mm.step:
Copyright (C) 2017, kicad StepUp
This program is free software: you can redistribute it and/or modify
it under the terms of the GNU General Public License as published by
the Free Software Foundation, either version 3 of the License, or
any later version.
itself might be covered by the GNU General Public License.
